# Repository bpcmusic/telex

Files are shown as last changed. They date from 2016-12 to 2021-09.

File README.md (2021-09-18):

# TELEX EURORACK EXPANDERS

The TELEX are a family of eurorack expanders that were initially designed to interface with the Monome Teletype to provide additional inputs and outputs. Utilizing the `II` bus (i2c) and having a flexible command set, there is no reason that these modules couldn't connect and extend other Monome Eurorack devices (even non-Eurorack devices that support II like the Aleph) or your own hardware projects.

Follow the conversation at [llllllll](http://llllllll.co/t/a-teletype-expander/1379).

## The Modules

The TELEXo (or TXo) is an output expander and the TELEXi (or TXi) is an input expander. They have little jumpers on the back so you can hook more than one of each module to your Teletype simultaneously. (Theoretically, up to eight of each type - though I’ve only tested six total modules at a time thus far. There will be a limit based on the II bus resistance - not sure what it is yet.)

* **TELEXo (TXo)**: a 4HP output module that provides 4 trigger outputs and 4 CV outputs addressable over `II`. Up to 8 can be independently addressed by the Teletype.

* **TELEXi (TXi)**: a 4HP input module that provides 4 control voltage potentiometers and 4 independent control voltage inputs. Up to 8 can be independently addressed by the Teletype.

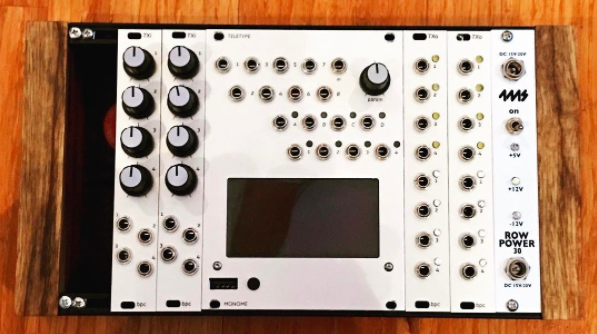
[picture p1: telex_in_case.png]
TELEX MODULES


## Teletype Firmware

We recommend the Teletype 2.0 BETA at this point. You can get it from this forum:

https://llllllll.co/t/teletype-2-0-beta-release-candidate-1-released-6th-june-2017/6939?u=bpcmusic

It is the bomb.

You can always head to Monome for the latest [Official Teletype Firmware](https://github.com/monome/teletype).

## TELEX Firmware

Download the latest TELEX firmware from the releases section of this site:

https://github.com/bpcmusic/telex/releases

### Installing Your Firmware

> **DO NOT POWER YOUR MODULE WHILE CONNECTING THE TEENSY VIA USB TO YOUR COMPUTER - THIS WOULD BE VERY BAD**

Ok. With that out of the way, here are some simple steps.

Firmware is loaded on the Teensy processor that piggybacks on the underside of your module. Doing so is pretty simple.

1. Download the Teensy Loader application for your operating system from https://www.pjrc.com/teensy/loader.html (if you don't have it already)
2. Download and unzip the latest TELEX firmware from https://github.com/bpcmusic/telex/releases
3. (optional) Carefully remove the Teensy from your module
4. Connect the Teensy to your computer via USB
5. Use your operating system specific instructions for the Teensy Loader to open the appropriate firmware in the Teensy loader and program it on your Teensy
6. Disconnect the Teensy from USB when the firmware has been loaded
7. Reattach the Teensy to your module if you removed it
8. Party.

### Compiling Your Own Firmware

Compiling the TELEX firmware is done using the [Arduino Development Environment](https://www.arduino.cc/en/Main/Software) and a few extensions.

* [Arduino Development Environment](https://www.arduino.cc/en/Main/Software)
* [Teensy-duino Add-On](https://www.pjrc.com/teensy/td_download.html)
* [i2c_t3 Library for Teensy](https://forum.pjrc.com/threads/21680-New-I2C-library-for-Teensy3)

Several additional libraries are included in the project due to the Arduino IDE's wonderful linking capabilities.

	IMPORTANT: overclock your Teensy 3.2 to 120 MHz in the IDE; Teensy 3.6 should be at 180 MHz

### Critical Startup Optimization for Compilation

> NOTE: this keeps changing in the Teensyduino application. I'm not finding this necessary anymore, but am leaving the old instructions in case anyone wants to fuss around with it. You can ignore for now.

If you want your TELEX to be ready when your Teletype has booted and is sending out the `I` script for the program that it is loading at startup, you need to make a change to the Teensy file "pins_teensy.c" in your Arduino hardware folder. For my mac, this is inside of the Arduino application package in:

`Contents\Java\hardware\teensy\avr\cores\teensy3\pins_teensy.c`

You need to change the values in the delay() calls - the original values are commented off to the right:

```
#if TEENSYDUINO >= 142
	delay(25);
	usb_init();
	delay(150); // 275
#else
	delay(50);
	usb_init();
	delay(125); // 350
#endif
```

For now, we edit this in-place. I know. We shuddered too. But, that seems to be the best way to make the change. Remember, you need to change it back for any other Arduino compilation you plan to do as it may have the device ready before all of your related components are - including the Teensy's USB interface.

## TELEX Command Reference

Reference documents for the commands supported by the TXo and TXi are located here:

* [Markdown Command Reference with Extra Descriptions](commands.md)
* [Printable Command Reference](extras/TELEX%20Command%20Reference.pdf)

The documents are a little behind the latest firmware; we're moving all operator definitions into the 2.0 documentation system which **is** up to date.

The latests ops are mentioned in this forum post, if you are curious. You need the 2.0 beta firmware (mentioned above) to access them.

https://llllllll.co/t/telex-teletype-expanders/1379/609?u=bpcmusic

## TELEXo

Each 4HP module adds 4 Trigger outputs and 4 Control Voltage outputs. 

All Teletype output functionality is supported by the TXo. Operators are near-identical for basic functionality, just put a "TO.” in front of the set you already know. The outputs are a little different; the triggers are +5V triggers and the CV outputs are bipolar (-10V to +10v) with 16 bit resolution over that range.

Extended functionality of the TXo starts with being able to specify longer values for slew and pulse times (in seconds and minutes). 

The TXo has the following “experimental” features for each of its four TR outputs:

- Configurable pulse dividers for each output
- Independent metronomes for each output that will pulse each output at intervals that can be set in milliseconds, seconds, minutes, and beats per minute (BPM)

The TXo also has the following “experimental” features for each of its four CV outputs:

- a quantizer with a dozen or so microtonal scales in addition to equal temperament
- an oscillator (not currently band-limited) that supports frequencies from LFO rates up to around 8kHz with variable morphing waveforms (sine, triangle, saw, variable width square, and noise), adjustable phase offset, and frequency slew (portamento)
- an AR (attack + release) envelope generator with times in milliseconds, seconds and minutes

These extended features, when combined together, can really push the envelope of the TXo’s processor and do some crazy stuff. For example: the output's envelope generator can act as a VCA, which turns the expander into a little 4-voice synth.

#### Links:

* [TXo Arduino Firmware](software/TELEXo)
* [TXo Module PCB](hardware/TELEXo/board)
* [TXo Module BOM](hardware/TELEXo/board/TELEXo-BOM.xlsx)
* [TXo 4HP Module Panel](hardware/TELEXo/panel)

## TELEXi

Each 4HP module adds 4 IN jacks and 4 PARAM knobs. 

* The IN jacks are bipolar (-10V to +10V).
* They jacks and knobs just like the Teletype IN and PARAM operators (TI.IN and TI.PARAM). 
* The TXi has some extended functionality where the TXi can do quantization for you and return note numbers against any one of its internal scales (there are about 12 or so). 
* Inputs are sampled with 13bit resolution.

#### Links:

* [TXo Arduino Firmware](software/TELEXi)
* [TXo Module PCB](hardware/TELEXi/board)
* [TXo Module BOM](hardware/TELEXi/board/TELEXi-BOM.xlsx)
* [TXo 4HP Module Panel](hardware/TELEXi/panel)

## Addressing Multiple TELEX Modules

Multiple TELEX modules are addressed using jumpers on the back of the unit. Theoretically, you can have up to eight of each type of unit on the same II bus. The addresses are non-conflicting between module types. For example, if you have one of each module, each would be unit #1 of that type and neither would have any address jumpers set.

The jumpers are oriented vertically and the rows are numbered from top to bottom:

* Row 1
* Row 2
* Row 3

Placing jumpers on rows in the following sequence allows you to designate the unit # (which is the binary representation of the rows plus one). X indicates the placement of a jumper.

| Row 1 | Row 2 | Row 3 | Unit # | Inputs/Outputs |
| --- | --- | --- | --- | --- |
| 0 | 0 | 0 | 1 | 1-4 |
| X | 0 | 0 | 2 | 5-8 |
| 0 | X | 0 | 3 | 9-12 |
| X | X | 0 | 4 | 13-16 |
| 0 | 0 | X | 5 | 17-20 |
| X | 0 | X | 6 | 21-24 |
| 0 | X | X | 7 | 25-28 |
| X | X | X | 8 | 28-32 |

## DIY Tips and Warnings

The modules are made up with two boards stacked on top of each other and a Teensy 3.2 riding piggyback. They are primarily 603 SMD parts with a few 805, 1206 and SMD ICs thrown in for good measure. If you have assembled any of mxmxmx’s DIY modules (Ornament + Crime, Terminal Tedium, etc.) you should have no problem with the expanders. They are not, however, a beginners project for SMD.

The DAC that is used for the TXo is the DAC8564 (Mouser P/N: 595-DAC8564ICPW; datasheet: http://www.ti.com/product/DAC8564). This part is used by a number of Eurorack modules - including Mutable's *Yarns* and *Ornament + Crime* by mxmxmx. It has tiny little SMD legs that can cause DIY cursing. ;)

#### Use the Build Maps

The build maps are PDF files that have one page per component per side per board showing you all the places that component goes. This saves a ton of time and avoids the pain-in-the-ass component hunt. They are linked below - but check out the example below:

Build Map Sample

Thanks to [c1t1zen](https://www.instagram.com/c1t1zen/) for the idea. :)

#### Crazy Board Naming

I have a goofy naming convention for the boards. It is confusing. But, I embraced the organic silliness. The "Top" Board is the one behind the panel. The "Bottom" Board is the one facing the back of your case. The side of the board with the name of the unit and board on it is considered the "Top" of the board. The other side is considered the bottom. This means The boards and sides are like this:

- **Top Top** - facing the panel; has the jacks, pots and LEDs
- **Top Bottom** - the back-side of the one facing the panel with a small handful of components
- **Bottom Bottom** - faces the Top Bottom on the "back board" of the unit
- **Bottom Top** - faces the back of your case; has the Teensy, power and jumpers mounted on it

Stupid, I know. But it makes a certain kind of back assward sense.

#### Balancing Headers IMPORTANT

In addition to the two signal headers that connect the boards, there are a pair of two pin connectors that provide balance at the top and the bottom of the boards. Keep the following tips in mind:

> The top connector for both modules needs to be installed before the component that it sits behind it is placed. The header pins on the Top Top side should be as near flush as possible. They aid in connecting both boards ground planes, so you don't want them shorting out to the jack (TXo) or the potentiometer (TXi). I actually trim them to be board-level prior to soldering so that they are as flat as possible. I also bend the front foot of the potentiometer (TXi) out of the way a bit so as to avoid contact.

#### Stencil Frames are your Friends

There are a bunch of 3D printable frames available for you to help your build process. As there are SMD components on both sides of the three of the four boards across the two modules, these frames help lay the boards flat for the application of solder paste and/or manual soldering of the components. They save you a ton of time and frustration. They are your friends.

There are also MULTI files for three of the dual-sided boards that will help you hold eight boards next to each other at a time. These are really handy if you are building in bulk. All of the files are in the stencil_frame folders inside of the hardware / board folders.

3D Prints were tested on a Prusa i3 MK2 with PLA filament.

### TXi Build Files

[Explore the repository for all kinds of support files](hardware/TELEXi). Here are some of the key ones:

* [TXi Schematic](hardware/TELEXi/board/Telex-I%20Schematic.pdf)
* [TXi Gerbers Top](hardware/TELEXi/board/gerbers/TI-TOP-1.1.zip)
* [TXi Gerbers Bottom](hardware/TELEXi/board/gerbers/TI-BOT%201.1A.zip)
* [TXi BOM](hardware/TELEXi/board/TELEXi-BOM.xlsx)
* [TXi Bottom Top Build Map](hardware/TELEXi/board/build_map/bt/txi_bt_build_map.pdf)
* [TXi Bottom Bottom Build Map](hardware/TELEXi/board/build_map/bb/txi_bb_build_map.pdf)
* [TXi Top Top Build Map](hardware/TELEXi/board/build_map/tt/txi_tt_build_map.pdf)
* [TXi Top Bottom Build Map](hardware/TELEXi/board/build_map/tb/txi_tb_build_map.pdf)
* [TXi Panel Files](hardware/TELEXi/panel)
* [TXi Stencil Frames](hardware/TELEXi/board/stencil_frame)

### TXo Build Files

[Explore the repository for all kinds of support files](hardware/TELEXo). Here are some of the key ones:

* [TXo Schematic](hardware/TELEXo/board/Telex-O%20Schematic.pdf)
* [TXo Gerbers Top](hardware/TELEXo/board/gerbers/TO-TOP-1.1.zip)
* [TXo Gerbers Bottom](hardware/TELEXo/board/gerbers/TO-BOT-1.1.zip)
* [TXo BOM](hardware/TELEXo/board/TELEXo-BOM.xlsx)
* [TXo Bottom Top Build Map](hardware/TELEXo/board/build_map/bt/txo_bt_build_map.pdf)
* [TXo Bottom Bottom Build Map](hardware/TELEXo/board/build_map/bb/txo_bb_build_map.pdf)
* [TXo Top Top Build Map](hardware/TELEXo/board/build_map/tt/txo_tt_build_map.pdf)
* [TXo Top Bottom Build Map](hardware/TELEXo/board/build_map/tb/txo_tb_build_map.pdf)
* [TXo Panel Files](hardware/TELEXo/panel)
* [TXo Stencil Frames](hardware/TELEXo/board/stencil_frame)

## Thanks
* Brian Crabtree and Kelli Cain for creating [Monome](http://monome.org) and their awesome, open Eurorack modules (including the Teletype which started this all).

* [Galapagoose](http://llllllll.co/users/galapagoose/activity) for being an endlessly patient mentor helping get the circuit design and layout sorted. These modules wouldn't exist without his help.

* [Tom Erbe](http://www.soundhack.com/) for teaching me all about this stuff at CalArts back in the dark ages.

* Ezra Buchla and Brian for birthing the beautiful and ambitious Aleph and endowing it with an `II` jack.

* Tom Whitwell of [Music Thing Modular](http://musicthing.co.uk/modular/) and his open sharing of the Teensy 3.1 powered, Bad-Assed [RadioMusic](https://github.com/TomWhitwell/RadioMusic/wiki).

* Émilie Gillet at [Mutable Instruments](http://mutable-instruments.net/) for her fantastic modules, excellent design, impressive implementation skills and commitment to open hardware. 

* Jim Matheson of Neutron Sound and his fantastic Teensy 3.1 powered [Orgone Accumulator](http://neutron-sound.com/noa.html).

* PJRC for making the awesome [Teensy](https://www.pjrc.com/teensy/index.html).

* The community at [llllllll](http://llllllll.co) for being so supportive and patient as I've lumbered my way through making these things.

---

These modules are open source. Hardware is released under the cc-by-sa-4.0 license and the source code is released under the MIT license.

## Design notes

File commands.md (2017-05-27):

# TELEX Command Reference

This document outlines the commands for the open source Teletype Expanders TELEXo and TELEXi. You can also use this [Printable Command Reference](extras/TELEX Command Reference.pdf).

#### Changelog

The document's version history - for those of you that follow along. ;)

**Revision v.13y** - 18 February 2017

* added TXo commands for setting repeat counter for TR.M events

**Revision v.13x** - 18 February 2017

* added TXi commands for mapping inputs and param knobs
* added TXo commands for setting cycle length and trigger length
* added TXo commands for setting repeat counter for TR.M events

**Revision v.13w** - 7 February 2017

* added [scanner_darkly](https://github.com/scanner-darkly)'s awesome morphing waveform support for WAVE
* added [scanner_darkly](https://github.com/scanner-darkly)'s super useful oscillator phase offset

**Revision v.13p** - 14 January 2017

* added the extended commands for TO.TR; four independent metronomes and pulse dividers

**Revision v.13c** - 7 January 2017

* changed the extended commands for TIME and SLEW to use a period (.) to delimit the seconds and minutes extensions. For example: TO.TR.TIME.S
* reduced the size of the CALLIBRATE to CALIB command for the TXo

**Revision v.13b** - 16 December 2016

* first version of the command reference document

#### Notes

* **Basic Commands** represent commands that have 1 to 1 equivalents in the Teletype command set
* **Extended Commands** represent commands that are new to the expanders but have close equivalents in the Teletype command set
* **Experimental Commands** are commands that are new functionality provided by the expanders; they push the expanders to the edge of performance and should be considered "dangerously fun"
* **n** represents the number of outputs or inputs that you have added to your Teletype (4 of each type for each expander)
* **x** represents the expander unit as opposed to an output (1 for each expander)
* **&alpha;** represents the value that you are supplying to an operator that takes a parameter
* **&alpha;** values for control voltages are *bipolar* on the TELEXo - they accept values between -16384 to 16383

## TELEXo (TXo)

#### TXo Trigger Output (TR) Basic Commands

Command  | Description 
------------- | ------------- 
TO.TR 1-n &alpha;   | Set TR value to &alpha; (0/1)    
TO.TR.TOG 1-n  | Toggle TR
TO.TR.PULSE 1-n | Pulse TR using TO.TR.TIME/S/M as an interval
TO.TR.TIME 1-n &alpha; | time for TR.PULSE; &alpha; in milliseconds
TO.TR.POL 1-n &alpha; | polarity for TO.TR.PULSE set to &alpha; (0-1)

#### TXo Trigger Output (TR) Extended Commands

Command  | Description 
------------- | ------------- 
TO.TR.TIME.S 1-n &alpha; | time for TR.PULSE; &alpha; in seconds
TO.TR.TIME.M 1-n &alpha; | time for TR.PULSE; &alpha; in minutes

#### TXo Trigger Output (TR) Experimental Commands - Divider + Metronomes

Command  | Description 
------------- | ------------- 
TO.TR.PULSE.DIV 1-n &alpha; | pulse divider for TR output; &alpha; in # of pulses
TO.TR.M 1-n &alpha; | time for TR.M; &alpha; in milliseconds
TO.TR.M.S 1-n &alpha; | time for TR.M; &alpha; in seconds
TO.TR.M.M 1-n &alpha; | time for TR.M; &alpha; in minutes
TO.TR.M.BPM 1-n &alpha; | time for TR.M; &alpha; in Beats Per Minute
TO.TR.M.ACT 1-n &alpha; | activates the metronome for the TR output; &alpha; (0=off; 1=on)
TO.TR.M.COUNT 1-n &alpha; | sets the number of repeats before deactivating (0=infinity)
TO.TR.M.SYNC 1-n | synchronizes the metronome on the device #
TO.TR.WIDTH 1-n &alpha; | time for TR.PULSE; &alpha; percentage of TR.M

#### TXo Control Voltage (CV) Basic Commands

Command  | Description 
------------- | ------------- 
TO.CV 1-n &alpha; | CV target &alpha; (bipolar)
TO.CV.SLEW 1-n &alpha; | CV slew time; &alpha; in milliseconds
TO.CV.SET 1-n &alpha; | set CV to &alpha; (bipolar); ignoring SLEW
TO.CV.OFF 1-n &alpha; | CV offset; &alpha; added at final stage 

#### TXo Control Voltage (CV) Extended Commands

Command  | Description 
------------- | ------------- 
TO.CV.SLEW.S 1-n &alpha; | CV slew time; &alpha; in seconds
TO.CV.SLEW.M 1-n &alpha; | CV slew time; &alpha; in minutes
TO.CV.QT 1-n &alpha; | CV target &alpha;; quantized to output's current CV.SCALE
TO.CV.QT.SET 1-n &alpha; | set CV to &alpha;; quantized to output's current CV.SCALE; ignoring SLEW
TO.CV.N 1-n &alpha; | CV target note # &alpha; in output's current CV.SCALE
TO.CV.N.SET 1-n &alpha; | set CV to note # &alpha; in output's current CV.SCALE; ignoring SLEW
TO.CV.SCALE 1-n &alpha; | select scale # &alpha; for individual CV output; see quantization scale reference below

#### TXo Control Voltage (CV) Experimental Commands - Oscillator Functions

Note: to start oscillation, set the frequency for the CV output to a value greater than zero. To return it to basic functionality, set it back to zero (0). When in oscillation mode, the current CV value sets the peak for the waveform - think of it like a volume or range control.

Command  | Description 
------------- | ------------- 
TO.OSC 1-n &alpha; | targets oscillation to &alpha; (1v/oct translated)
TO.OSC.SET 1-n &alpha; | sets oscillation to &alpha;; ignores OSC.SLEW
TO.OSC.QT 1-n &alpha; | targets oscillation to &alpha; (1v/oct translated); quantized to current OSC.SCALE
TO.OSC.QT.SET 1-n &alpha; | sets oscillation to &alpha; in current OSC.SCALE; ignores OSC.SLEW
TO.OSC.N 1-n &alpha; | targets oscillation to note # &alpha;; quantized to current OSC.SCALE
TO.OSC.N.SET 1-n &alpha; | sets oscillation to note # &alpha; in current OSC.SCALE; ignores OSC.SLEW
TO.OSC.FQ 1-n &alpha; | targets oscillation to frequency &alpha; in Hz
TO.OSC.FQ.SET 1-n &alpha; | sets oscillation to frequency &alpha; in Hz; ignores OSC.SLEW
TO.OSC.LFO 1-n &alpha; | targets oscillation to frequency &alpha; in mHz (millihertz: 10^-3 Hz)
TO.OSC.LFO.SET 1-n &alpha; | sets oscillation to frequency &alpha; in mHz (millihertz: 10^-3 Hz); ignores OSC.SLEW
TO.OSC.WAVE 1-n &alpha; | set the waveform to sine (0), triangle (1000), saw (2000), pulse (3000), or noise (4000). Range is from 0 to 4999. Oscillator shape is blended in between the "pure" values.
TO.OSC.SYNC 1-n | resets the phase of the oscillator to zero
TO.OSC.PHASE 1-n &alpha; | sets the phase offset of the oscillator to &alpha; (0 to 16384) - range of one cycle;
TO.OSC.WIDTH 1-n &alpha; | sets the width of the pulse  wave (3) to &alpha; (0 to 100)
TO.OSC.RECT 1-n &alpha; | rectifies the polarity of the oscillator to &alpha; (-2 to 2); see rectification reference
TO.OSC.SLEW 1-n &alpha; | sets the slew time for the oscillator (portamento) to &alpha; (milliseconds)
TO.OSC.SLEW.S 1-n &alpha; | sets the slew time for the oscillator (portamento) to &alpha; (seconds)
TO.OSC.SLEW.M 1-n &alpha; | sets the slew time for the oscillator (portamento) to &alpha; (minutes)
TO.OSC.SCALE 1-n &alpha; | sets the quantization scale for the oscillator to scale # &alpha; (listed below)
TO.OSC.CYC 1-n &alpha; | targets the cycle length for the oscillator to &alpha; (milliseconds)
TO.OSC.CYC.S 1-n &alpha; | targets the cycle length for the oscillator to &alpha; (seconds)
TO.OSC.CYC.M 1-n &alpha; | targets the cycle length for the oscillator to &alpha; (minutes)
TO.OSC.CYC.SET 1-n &alpha; | sets the cycle length for the oscillator to &alpha; (milliseconds)
TO.OSC.CYC.S.SET 1-n &alpha; | sets the cycle length for the oscillator to &alpha; (seconds)
TO.OSC.CYC.M.SET 1-n &alpha; | sets the cycle length for the oscillator to &alpha; (minutes)

#### TXo Control Voltage (CV) Experimental Commands - Envelope Generator

Note: when you activate the envelope (using ENV.ACT) your CV output will drop to zero. You need to trigger the envelope (ENV.TRIG) in order to get it to play. This will interact with your currently set CV value for the output making that the (bipolar capable) peak for the envelope. Also, this will interact with the oscillator as well and become a virtual VCA for its output.

Command  | Description 
------------- | ------------- 
TO.ENV.ACT 1-n &alpha; | activates the envelope generator for the CV output; &alpha; (0 = off; 1 = on)
TO.ENV.ATT 1-n &alpha; | attack time for the envelope; &alpha; in milliseconds
TO.ENV.ATT.S 1-n &alpha; | attack time for the envelope; &alpha; in seconds 
TO.ENV.ATT.M 1-n &alpha; | attack time for the envelope; &alpha; in minutes
TO.ENV.DEC 1-n &alpha; | decay time for the envelope; &alpha; in milliseconds 
TO.ENV.DEC.S 1-n &alpha; | decay time for the envelope; &alpha; in seconds
TO.ENV.DEC.M 1-n &alpha; | decay time for the envelope; &alpha; in minutes
TO.ENV.TRIG 1-n | triggers the envelope to play

#### TXo Global Commands

This command affects both trigger (TR) and control voltage (CV) outputs.

Command  | Description 
------------- | ------------- 
TO.KILL | cancels TR pulses and CV slews 

#### Rectification Reference

There are several rectification modes available in the oscillator. They are listed below:

Mode | Behavior
--- | ---
-2 | inverts positive values making them negative
-1 | omits all positive values
0 | no rectification; wave is unaffected bipolar
1 | omits all negative values
2 | inverts negative values making them positive

## TELEXi (TXi)

#### TXi Basic Commands

Command  | Description 
------------- | ------------- 
TI.IN 1-n | reads the value of the CV input jack (-16384 to 16383)
TI.PARAM 1-n | reads the value of the PARAM knob (0 to 16383) 

#### TXi Extended Commands

Command  | Description 
------------- | ------------- 
TI.IN.QT 1-n | return the quantized value for the IN jack; uses input's IN.SCALE
TI.IN.N 1-n | return the quantized note number for the IN jack; uses the input's IN.SCALE
TI.IN.SCALE 1-n &alpha; | sets the current scale for the input to &alpha;; see scale reference below
TI.IN.MAP 1-n &alpha; &beta; | maps the IN values to the range &alpha; - &beta;
TI.PARAM.QT 1-n | return the quantized value for the PARAM knob; uses knob's PARAM.SCALE
TI.PARAM.N 1-n | return the quantized note number for the PARAM knob; uses knob's PARAM.SCALE
TI.PARAM.SCALE 1-n &alpha; | sets the current scale for the param knob to &alpha;; see scale reference below
TI.PARAM.MAP 1-n &alpha; &beta; | maps the PARAM values to the range &alpha; - &beta;

#### TXi Experimental Commands

The calibration settings allow you to scale your input values for the IN jacks and the PARAM knobs to compensate for component tolerances. The calibration procedures are listed in the Calibration Details section.

*NOTE: Only the TXi currently has calibration capabilities; these features have not been implemented for the TXo for performance reasons - though, if they are desired, it would be possible to port them over. Go Open Source!*

Command  | Description 
------------- | ------------- 
TI.IN.CALIB 1-n &alpha; | calibrates the scaling for the IN jack; see calibration details below
TI.PARAM.CALIB 1-n &alpha; | calibrates the scaling for the PARAM knob; see calibration details below
TI.STORE 1-x | stores the calibration data for the expander to its flash memory
TI.RESET 1-x | resets the calibration data to factory defaults

#### TXi Calibration Details

Calibration for the input module works as follows:

**IN Calibration**

1. Send a -10V signal to the input Z
2. Send the command 'TI.IN.CALIBRATE Z -1'
3. Send a 0V signal to the input Z
4. Send the command 'TI.IN.CALIBRATE Z 0'
5. Send a 10V signal to the input Z
6. Send the command 'TI.IN.CALIBRATE Z 1'

**PARAM Calibration**

1. Turn the PARAM knob Z all the way to the left
2. Send the command 'TI.PARAM.CALIBRATE Z 0'
3. Turn the PARAM knob Z all the way to the right
4. Send the command 'TI.PARAM.CALIBRATE Z 1'

**Save and Reset**

* You can save the calibration data for a device by sending 'TI.STORE N'. N is the number of the device - not the number of an input.

* You can reset the calibration data for a device by sending 'TI.RESET N'. N is the number of the device - not the number of an input.

## Quantization Scale Reference

Scale Number | Scale Name
--- | ---
0 | Standard 12 Tone Equal Temperament **[DEFAULT]** 
1 | 12-tone Pythagorean scale
2 | Vallotti & Young scale (Vallotti version) also known as Tartini-Vallotti (1754)
3 | Andreas Werckmeister's temperament III (the most famous one, 1681)
4 | Wendy Carlos' Alpha scale with perfect fifth divided in nine
5 | Wendy Carlos' Beta scale with perfect fifth divided by eleven
6 | Wendy Carlos' Gamma scale with third divided by eleven or fifth by twenty
7 | Carlos Harmonic & Ben Johnston's scale of 'Blues' from Suite f.micr.piano (1977) & David Beardsley's scale of 'Science Friction'
8 | Carlos Super Just
9 | Kurzweil "Empirical Arabic"
10 | Kurzweil "Just with natural b7th", is Sauveur Just with 7/4
11 | Kurzweil "Empirical Bali/Java Harmonic Pelog"
12 | Kurzweil "Empirical Bali/Java Slendro, Siam 7"
13 | Kurzweil "Empirical Tibetian Ceremonial"
14 | Harry Partch's 43-tone pure scale
15 | Partch's Indian Chromatic, Exposition of Monophony, 1933.
16 | Partch Greek scales from "Two Studies on Ancient Greek Scales" on black/white

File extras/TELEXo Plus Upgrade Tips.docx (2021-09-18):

Thanks for grabbing a TXo+ Upgrade – the upgrade for those with discerning tastes in output expanders. This kit includes a hand-modified Teensy 3.6 and a bunch of capacitors that you don’t really need. No worries on that last part; all will be explained below.

What to Expect

When running on the Teensy 3.6, the TXo firmware does a few new things:

- Improved Sampling Rate - increased to 25kHz from the TXo’s 15.625kHz
- Improved Quality when Combining Features with Oscillation - the stock TXo disables interpolation if more than one advanced feature is used at a time for a CV output (envelopes, wave morphing, pitch slew, etc). The TXo+ always uses interpolation which increases the accuracy and lowers distortion.
- Enhanced sawtooth and square waves using the PolyBlep technique in order to reduce aliasing.
- More Morphing Wavetables - the TXo+ has 327 different waveforms on board (up from the TXo’s 45). Values range between 0 and 32699. Every 100 you get another “pure” waveform. 32600 should be random noise.

The commands are the same between the TXo and the TXo+. The only difference is the TO.OSC.WAVE as mentioned above. You don’t have to learn anything else if you are familiar with your TXo.

Now, here is the important bit: your TXo will still alias like crazy when used as an oscillator without additional filtration. It was designed as a CV device and only lightly filters the output. You might like the sound this way. I do.

You can clean things up with the right additional filtration (at 12.5k). This primarily will benefit the primitives (sine, square, saw, and triangle); extended waveforms will still alias as the expander doesn’t have the horsepower to oversample.

How to Install the Upgrade

There are two ways for you to do this. The reasonable way and the ridiculous way. The ridiculous way, while being ridiculous, includes the steps of the reasonable way. So, as with all things, let’s start reasonable and then get ridiculous.

Reasonable Install Steps

1. Carefully extract your TXo from your case.
2. Make sure you are grounded and not full of static electricity. (Good idea to banish the cat until you are done.)
3. Grip the Teensy processor on the back and delicately lift it out of its socket with even force on both sides. You might need to rock it a bit – just don’t do too much of that or you will bend the pins.
4. Remove the Teensy 3.6 with attached TeensyHelper from the antistatic bag.
5. Insert the old Teensy 3.2 into the empty antistatic bag and seal it.
6. Carefully insert the Teensy 3.6 into headers on the TXo body with the same orientation as the previous Teensy. (USB socket facing up and SD card facing down relative to the module.)
7. Make sure everything is seated properly and happy – including the various boards of your TXo.
8. Connect up your module to power and i2c and run a test to see if you get blinking lights and signal. (See “troubleshooting” below if you have problems.)
9. Reinstall your module.
10. Party.

Ridiculous Install Steps

This part is stupid. Best you ignore it.

We’ve included four capacitors with your upgrade. Trust us when we say that you don’t need them. Like, not at all. You won’t hear a difference. You won’t see a difference. You will more likely bork your TXo if you try to swap them out.

Why did we include them? We are asking ourselves the same question.

Maybe it was to torture you? We know that they would bug you. Disappoint you that they aren’t installed. That having them in your studio would be a constant reminder of incompleteness. A reminder of how your TXo+ is less than other TXo+ in the world.

Nah. They really don’t matter.

We included them for the sake of completeness – which for some reason is important to us. What they do is raise the cutoff point of the 1-pole filter on the TXo’s output so that it matches the new sampling rate. How much? Not much. Somewhere between 4-5 kHz.

Now, when you hear filter you are most likely thinking Filter. That’s not what we are talking about here. A 1-pole filter is a wimpy thing with a super gradual cutoff. It gets beat up after school. It has self-esteem problems. This is why we recommend more filtration if you want to get pure tones out of your TXo+.

We’ve included six capacitors that swap out for C102, C2, C3, and C4 on the TXo. Does your head hurt now? Think we can’t count? Come on; we included two extra just in case you sneeze while futzing when them (even though we told you not to).

Anyway, you can find all of the details on the github page for the module. We’re not including it here in order to avoid tempting you to try to swap them out – because you don’t need to.

Like, don’t. Just let it be.

You really don’t need them.

Troubleshooting

Your upgrade was installed and tested at our factory and should be in great shape. That is what the little orange dot means on the SD card.

Ok. it isn’t a “factory”, per se. It is a messy-as-hell guest bedroom that has never accommodated a guest - outside of the four-legged and furry kind.

Regardless, it was working when we sent it. The most common problem we have seen is with the machined headers that connect the two units. Sometimes they are so perfectly aligned that a pin or two makes poor contact. This will manifest itself in no CV (all values at -10), a trigger that doesn’t fire, an LED or two that doesn’t light up, or an unresponsive module.

The way to correct this is to provide a very slight bend to pins, alternating the direction (in vs out) until everything is happy. They are delicate, so you have to be extremely careful when doing this. Do them one at a time and test that you can still seat the processor.

Any other problems? Give a shout on lines (https://llllllll.co/) in the TELEX thread.

GOOD LUCK!!

b

TELEXo Plus Upgrade

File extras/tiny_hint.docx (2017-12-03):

A TINY HINT

Ensure that your TELEX boards and processor are properly seated after shipment. This is also a good thing to do after handling of any kind. Frankly, checking that your boards are properly connected should be the first thing you do if your unit seems unresponsive.

AN EVEN SMALLER HINT

If you are planning to travel with your TELEX, consider using thread or small rubber bands to keep the boards well-seated during rough travel. Superglue, chewing gum, and duct tape are not recommended for this purpose.

A LUDICROUSLY SMALL HINT

If you want your TELEX to be as thin and as securely assembled as possible, some people have desoldered the female headers and then soldered the boards together. Please, don’t try this if you don’t know what you are doing and have the proper equipment. Regardless, we take no responsibility for the chaos you cause in attempting this. If you and your pets survive, share some pictures!

A TINY HINT

Ensure that your TELEX boards and processor are properly seated after shipment. This is also a good thing to do after handling of any kind. Frankly, checking that your boards are properly connected should be the first thing you do if your unit seems unresponsive.

AN EVEN SMALLER HINT

If you are planning to travel with your TELEX, consider using thread or small rubber bands to keep the boards well-seated during rough travel. Superglue, chewing gum, and duct tape are not recommended for this purpose.

A LUDICROUSLY SMALL HINT

If you want your TELEX to be as thin and as securely assembled as possible, some people have desoldered the female headers and then soldered the boards together. Please, don’t try this if you don’t know what you are doing and have the proper equipment. Regardless, we take no responsibility for the chaos you cause in attempting this. If you and your pets survive, share some pictures!

A TINY HINT

Ensure that your TELEX boards and processor are properly seated after shipment. This is also a good thing to do after handling of any kind. Frankly, checking that your boards are properly connected should be the first thing you do if your unit seems unresponsive.

AN EVEN SMALLER HINT

If you are planning to travel with your TELEX, consider using thread or small rubber bands to keep the boards well-seated during rough travel. Superglue, chewing gum, and duct tape are not recommended for this purpose.

A LUDICROUSLY SMALL HINT

If you want your TELEX to be as thin and as securely assembled as possible, some people have desoldered the female headers and then soldered the boards together. Please, don’t try this if you don’t know what you are doing and have the proper equipment. Regardless, we take no responsibility for the chaos you cause in attempting this. If you and your pets survive, share some pictures!

A TINY HINT

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

AN EVEN SMALLER HINT

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

A LUDICROUSLY SMALL HINT

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

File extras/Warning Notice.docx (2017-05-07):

WARNING

DO NOT connect your module’s Teensy processor to USB while it is connected to Eurorack power. This will cause bad things to happen. Chernobyl-style bad things. Resist the temptation.

To upgrade your firmware, disconnect your module or simply remove the Teensy from the back of the module and connect it to your computer. Follow the procedure for loading firmware onto the Teensy that is appropriate for your operating system.

If you wish to debug the module via USB, you will need to separate VIN from VUSB on the underside of the Teensy. This is a simple procedure that should be done carefully to ensure that you don’t damage your Teensy, module, computer, or fabric of the universe.

TELEX Addendum 20170107-091371c

WARNING

DO NOT connect your module’s Teensy processor to USB while it is connected to Eurorack power. This will cause bad things to happen. Chernobyl-style bad things. Resist the temptation.

To upgrade your firmware, disconnect your module or simply remove the Teensy from the back of the module and connect it to your computer. Follow the procedure for loading firmware onto the Teensy that is appropriate for your operating system.

If you wish to debug the module via USB, you will need to separate VIN from VUSB on the underside of the Teensy. This is a simple procedure that should be done carefully to ensure that you don’t damage your Teensy, module, computer, or fabric of the universe.

TELEX Addendum 20170107-091371c

WARNING

DO NOT connect your module’s Teensy processor to USB while it is connected to Eurorack power. This will cause bad things to happen. Chernobyl-style bad things. Resist the temptation.

To upgrade your firmware, disconnect your module or simply remove the Teensy from the back of the module and connect it to your computer. Follow the procedure for loading firmware onto the Teensy that is appropriate for your operating system.

If you wish to debug the module via USB, you will need to separate VIN from VUSB on the underside of the Teensy. This is a simple procedure that should be done carefully to ensure that you don’t damage your Teensy, module, computer, or fabric of the universe.

TELEX Addendum 20170107-091371c

WARNING

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

TELEX Addendum 20170107-091371c

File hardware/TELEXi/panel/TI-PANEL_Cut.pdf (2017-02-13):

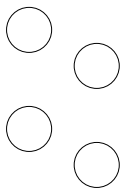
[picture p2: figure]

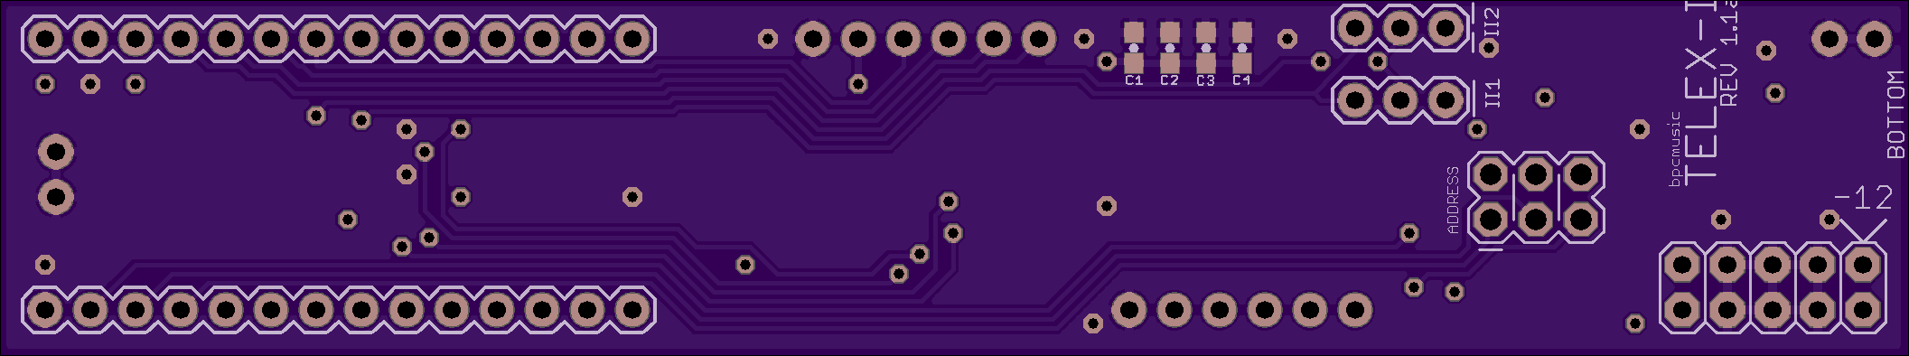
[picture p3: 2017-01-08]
hardware/TELEXi/board/images/TXi_Bottom_Top.png

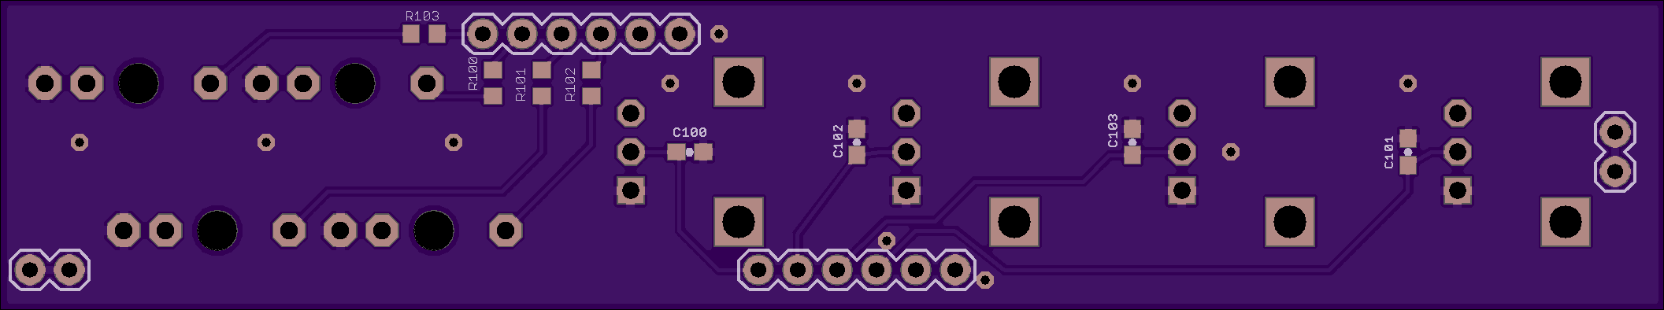
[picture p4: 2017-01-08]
hardware/TELEXi/board/images/TXi_Top_Bottom.png

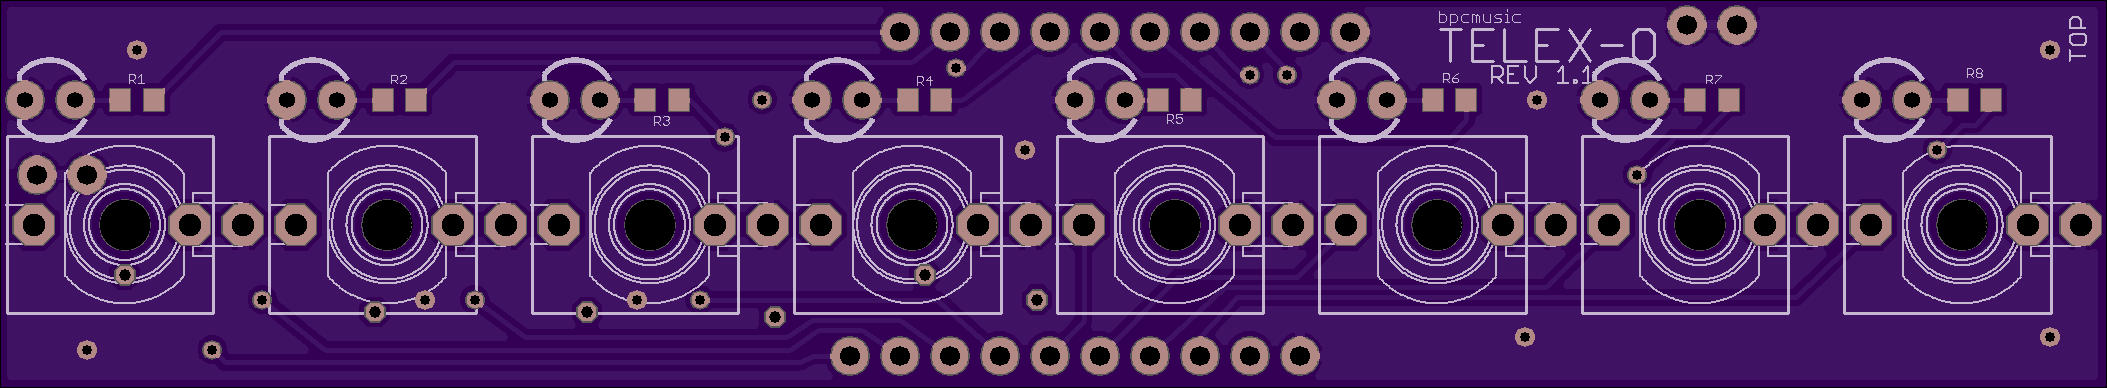
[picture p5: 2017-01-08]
hardware/TELEXo/board/images/TXo_Top_Top.png

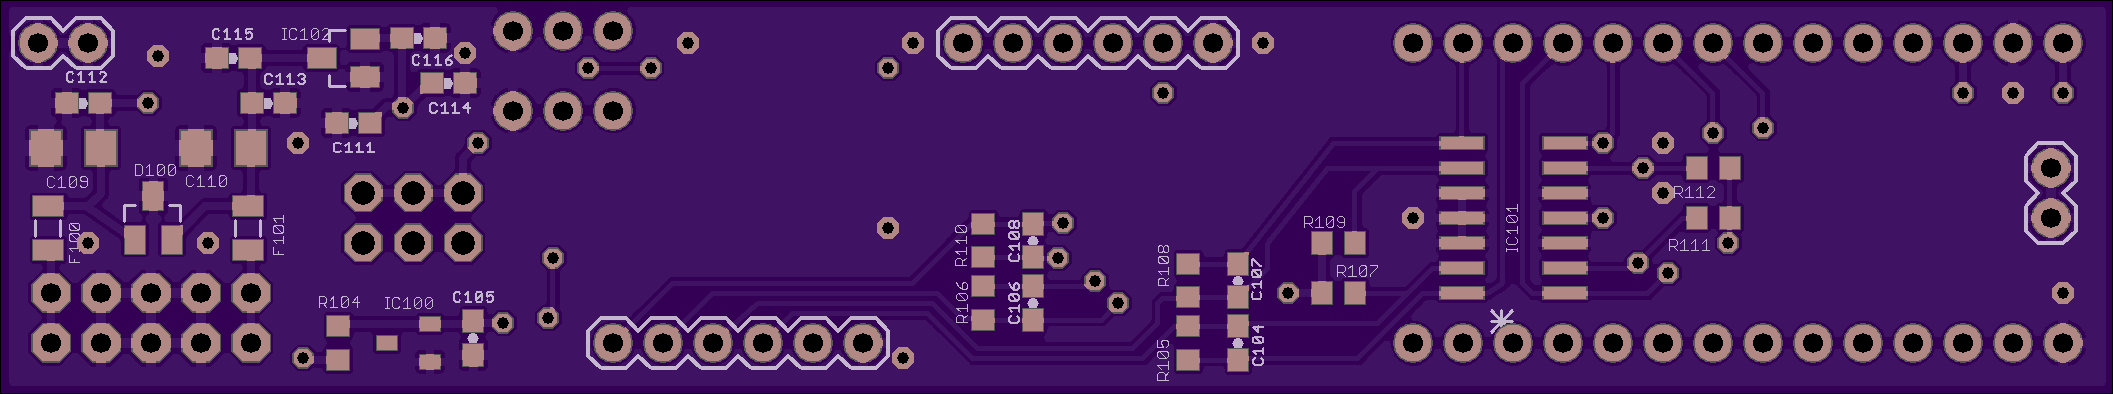
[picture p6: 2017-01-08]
hardware/TELEXi/board/images/TXi_Bottom_Bottom.png

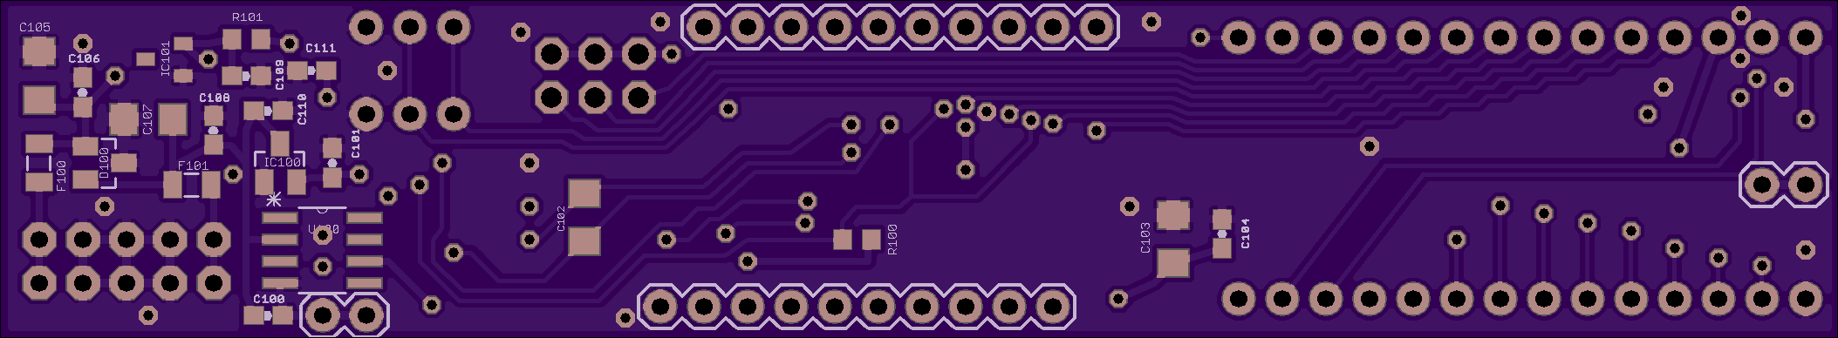
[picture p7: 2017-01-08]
hardware/TELEXo/board/images/TXo_Bottom_Bottom.png

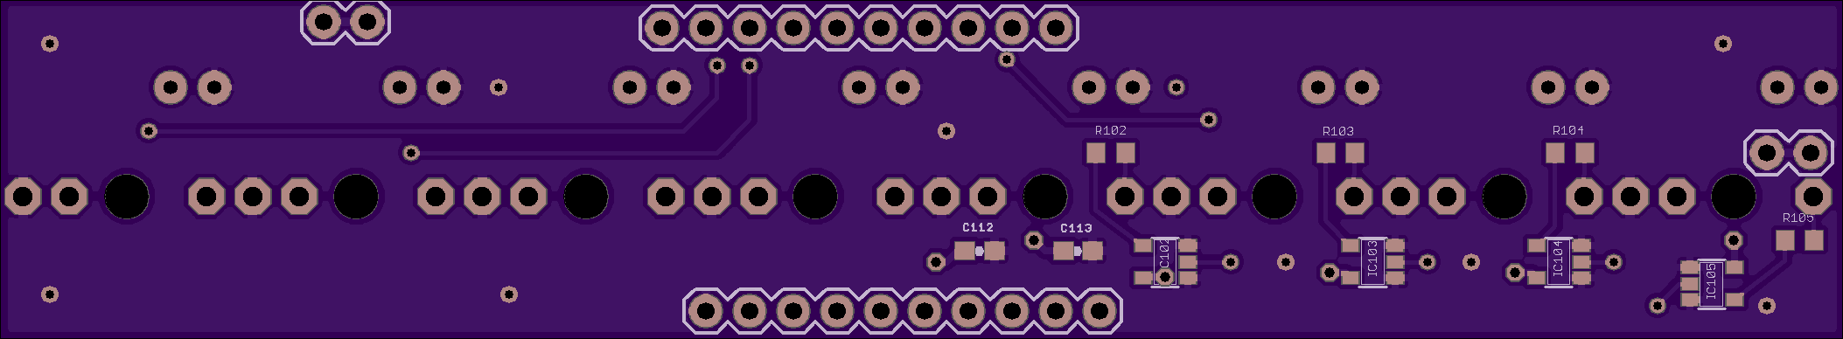
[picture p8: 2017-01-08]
hardware/TELEXo/board/images/TXo_Top_Bottom.png

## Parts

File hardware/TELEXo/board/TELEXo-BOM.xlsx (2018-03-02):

Qty | Value | Device | Package | Description | TopTop | TopBottom | BottomBottom | BottomTop | OC_MOUSER | URL | Notes
2 | 0805L010 | 0805L010 | 0805L | Polyfuse Resettable PTC |  |  | F100,F101 |  | 576-0805L010
2 | 1x03 MALE | 1x03M | 1x03M | 1x3 Header, Male |  |  |  |  |  |  | i2c Connectors; Standard Headers
2 | 1x10 FEMALE | 1x10F | 1x10F | 1x10 Header, Female |  |  |  |  |  |  | Board Interconnects; Safe to Substutite Machined Headers
2 | 1x10 MALE | 1x10M | 1x10M | 1x10 Header, Male |  |  |  |  |  |  | Board Interconnects; Safe to Substutite Machined Headers
2 | 1x14 FEMALE | 1x14F | 1x14F | 1x14 Header, Female |  |  |  |  |  |  | Teensy Interconnects; Safe to Substitute Machined Headers
2 | 1x14 MALE | 1x14M | 1x14M | 1x14 Header, Male |  |  |  |  |  |  | Teensy Interconnects; Safe to Substitute Machined Headers
1 | 2x03 MALE | 2x03M | 2x03M | 2x3 Header, Male |  |  |  |  |  |  | Jumpers; Standard Headers
1 | 2x05 MALE | 2x05M | 2x05M | Europower 2x5 |  |  |  |  |  |  | Europower Connector
4 | 74AHCT1G125DBV | 74AHCT1G125DBV | SOT23-5 | Single Bus Buffer Gate |  | IC102,IC103,IC104,IC105 |  |  | 595-SNAHCT1G125DBVR
1 | BAS70-04 | BAS70-04 | SOT23 | Schottky Diodes |  |  | D100 |  | 771-BAS70-04-T/R
8 | .1u | CAP0603-CAP | 0603-CAP | Capacitor; >=16V; 5% |  | C112,C113 | C100,C104,C106,C108,C109,C111 |  | 581-06033C104JAT2A
1 | .22u | CAP0603-CAP | 0603-CAP | Capacitor; >=16V; 10% |  |  |  | C1 | 810-C1608X7R1H224KAE
2 | 1u | CAP0603-CAP | 0603-CAP | Capacitor; >=16V; 10% |  |  | C101,C110 |  | 81-GCJ188R71E105KA1D
2 | 10uf | CAP1206 | 1206 | Capacitor; >=16V; 10% |  |  | C105, C107 |  | 81-GRM31CR71E106KA12
4 | 180p | CAP1206 | 1206 | Capacitor; >=16V; 1% |  |  | C102 | C2,C3,C4 | 77-VJ1206A181FXACBC |  | Substitue 110p if you plan to use a Teensy 3.6; Mouser PN 80-C1206C111J1G
1 | 3.3u | CAP1206 | 1206 | Capacitor; >=16V; 10% |  |  | C103 |  | 810-C3216X7R1H335K
1 | DAC8564 | DAC8564 | SOP65P640X120-16N | DAC |  |  |  | U1 | 595-DAC8564ICPW
8 | EURO_JACKS-7 | EURO_JACKS-7 | WQP_PJ_301M | Thonkiconn 3.5mm |  |  |  |  |  | https://www.thonk.co.uk/shop/3-5mm-jacks/ | "Thonkiconn"; don't forget to get the nut style of your choice. Erthenvar carries these in the USA.
4 | LED3MM WHITE | LED3MM | LED3MM | 3MM White LED |  |  |  |  |  | https://www.taydaelectronics.com/leds/round-leds/3mm-leds/white/led-3mm-white-water-clear-ultra-bright.html | Forward Voltage(V): 3.2-3.4; Current(MA): 20; Luminous intensity(MCD): 14,000 - 16,000
4 | LED3MM YELLOW | LED3MM | LED3MM | 3MM Yellow LED |  |  |  |  |  | https://www.taydaelectronics.com/leds/round-leds/3mm-leds/yellow/led-3mm-yellow.html | Forward voltage(V): 2.0-2.3; Current(mA): 20; Luminous intensity(MCD): 2,000 - 3,000
1 | LM4040A10IDBZR | LM4041A12DBZ | DBZ_R-PDSO-G3 | 10V Reference |  |  | IC101 |  | 595-LM4040C10IDBZR
1 | MCP1703AT-5002E/CB | MCP1703CB | SOT23 | 5V Regulator |  |  | IC100 |  | 579-MCP1703AT5002ECB
1 | 470 | R-US_R0603 | R0603 | Resistor .1% |  |  | R101 |  | 660-RN731JTTD4700B25
8 | 10k | R-US_R0603 | R0603 | Resistor 1% | R1,R2,R3,R4,R5,R6,R7,R8 |  |  |  | 71-CRCW0603-10K-E3
8 | 120k | R-US_R0603 | R0603 | Resistor .1% |  |  | R100 | R13,R15,R18,R19,R21,R22,R23 | 71-TNPW0603120KBEEA
4 | 15k | R-US_R0603 | R0603 | Resistor .05% |  |  |  | R9,R10,R11,R12 | 667-ERA-3ARW153V
8 | 1k | R-US_R0603 | R0603 | Resistor .1% |  | R102,R103,R104,R105 |  | R14,R16,R17,R20 | 652-CRT0603BY1001EAS
1 | REF02AU | REF02AU | SOIC127P600X175-8N | 5V Voltage Reference |  |  | U100 |  | 595-REF02AU
1 | TEENSY3.1_ALL | TEENSY3.1_ALL | TEENSY3.1_ALL | Teensy 3.2
1 | OPA4171 | TL074D | SO14 | Op Amp |  |  |  | IC1 | 595-OPA4171AIDR

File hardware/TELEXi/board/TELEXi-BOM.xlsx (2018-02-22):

Qty | Value | Device | Package | Description | TopBottom | BottomTop | BottomBottom | OC_MOUSER | URL | Notes
2 | 0805L010 | 0805L010 | 0805L | Fuses |  |  | F100,F101 | 576-0805L010
2 | 1x03 MALE | 1x03M | 1X03M | 1x3 Header, Male |  |  |  |  |  | i2c Connectors; Standard Headers
2 | 1x06 FEMALE | 1x06F | 1X06F | 1x6 Header, Female |  |  |  |  |  | Board Interconnects; Safe to Substutite Machined Headers
2 | 1x06 MALE | 1x06M | 1X06M | 1x6 Header, Male |  |  |  |  |  | Board Interconnects; Safe to Substutite Machined Headers
2 | 1x14 FEMALE | 1x14F | 1X14F | 1x14 Header, Female |  |  |  |  |  | Teensy Interconnects; Safe to Substitute Machined Headers
2 | 1x14 MALE | 1x14M | 1X14M | 1x14 Header, Male |  |  |  |  |  | Teensy Interconnects; Safe to Substitute Machined Headers
1 | 2x03 MALE | 2x03M | 2x03M | 2x3 Header, Male |  |  |  |  |  | Jumpers; Standard Headers
1 | 2x05 MALE | 2x05M | 2x05M | 5x2 Europower, Male |  |  |  |  |  | Europower Connector
4 | ALPHA-9MMF2A | ALPHA-9MMF2A | EVUF | B10K Pot |  |  |  |  | https://www.thonk.co.uk/shop/alpha-9mm-pots-vertical-t18/ | B10K Linear Potentiometer; I use the T18 Shaft. Synthrotek also carries these in the USA
4 | Knobs & Caps | KNOB | Small Black Skirted | Selco Knob |  |  |  |  | https://www.thonk.co.uk/shop/intellijel-style-knobs/ | Small Black Skirted T18 Knob and Small Grey Caps
1 | BAS70-04 | BAS70-04 | SOT23 | Schottky Diodes |  |  | D100 | 771-BAS70-04-T/R
10 | .1u | CAP0603-CAP | 0603-CAP | Capacitor; >=16V; 5% | C100, C101, C102, C103 | C1,C2 | C105,C112,C113,C114 | 581-06033C104JAT2A
1 | .01u | CAP0603-CAP | 0603-CAP | Capacitor; >=16V; 10% |  | C3 |  | 80-C0603C103K5REAUTO
4 | 4,700p | CAP0603-CAP | 0603-CAP | Capacitor; >=16V; 5% |  |  | C104,C106,C107,C108 | 81-GRM1885C1H472JA1D
4 | 1u | CAP0603-CAP | 0603-CAP | Capacitor; >=16V; 10% |  | C4 | C111,C115,C116 | 581-06033C105KAT2A
2 | 10uf | CAP1206 | 1206-CAP | Capacitor; >=16V; 10% |  |  | C109,C110 | 81-GRM31CR71E106KA12
4 | EURO_JACKS-7 | EURO_JACKS-7 | WQP_PJ_301M | Thonkiconn 3.5mm |  |  |  |  | https://www.thonk.co.uk/shop/3-5mm-jacks/ | "Thonkiconn"; don't forget to get the nut style of your choice. Erthenvar carries these in the USA.
1 | LM4040A10IDBZR | LM4041A12DBZ | DBZ_R-PDSO-G3 | 10V Reference |  |  | IC100 | 595-LM4040C10IDBZR
1 | MCP1703CB | MCP1703CB | SOT23 | 5V Regulator |  |  | IC102 | 579-MCP1703AT5002ECB
8 | 200k | R-US_R0603 | R0603 | Resistor .1% | R100,R101,R102,R103 |  | R107,R109,R111,R112 | 667-ERA-3AEB204V
4 | 33k | R-US_R0603 | R0603 | Resistor .1% |  |  | R105, R106, R108, R110 | 667-ERA-3AEB333V
1 | 470 | R-US_R0603 | R0603 | Resistor .1% |  |  | R104 | 660-RN731JTTD4700B25
1 | TEENSY 3.2 | TEENSY 3.2 | TEENSY 3.2 | Teensy 3.2 |  |  |  |  | https://store.oshpark.com/products/teensy-3-1 | OSH Park has the best price on Teensy 3.2. Plus, they are purple which makes the TELEX sound better.
1 | MCP6004 | TL074D | SO14 | Op Amp |  |  | IC101 | 579-MCP6004T-I/SL

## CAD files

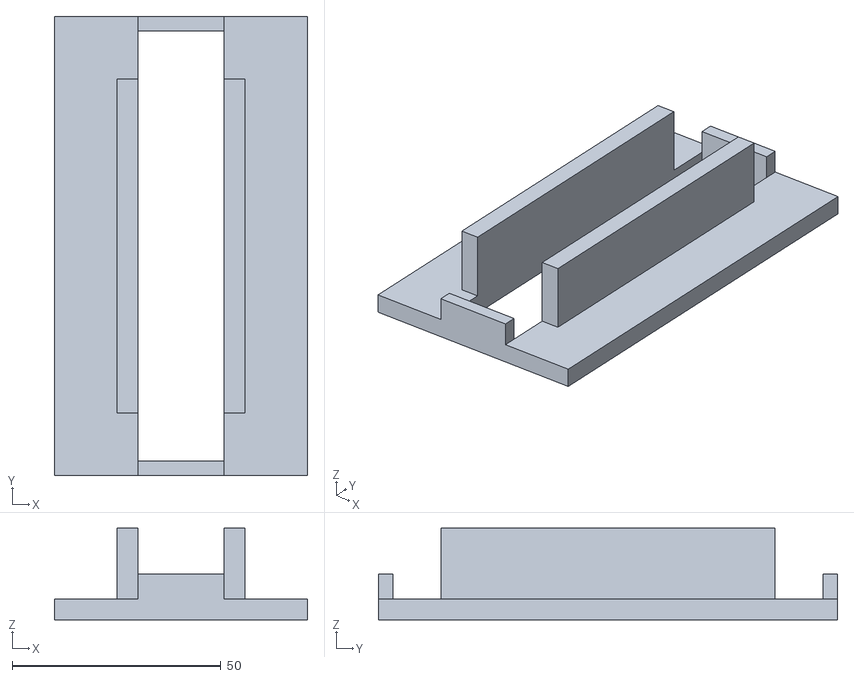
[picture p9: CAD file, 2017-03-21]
extras/assembly_frame.stl
60.6 x 110.0 x 22.0

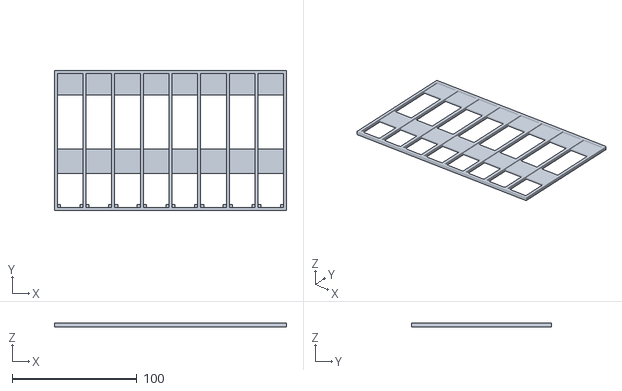
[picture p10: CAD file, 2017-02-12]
hardware/TELEXi/board/stencil_frame/txi_bottom_multi.stl
186.2 x 112.3 x 3.20

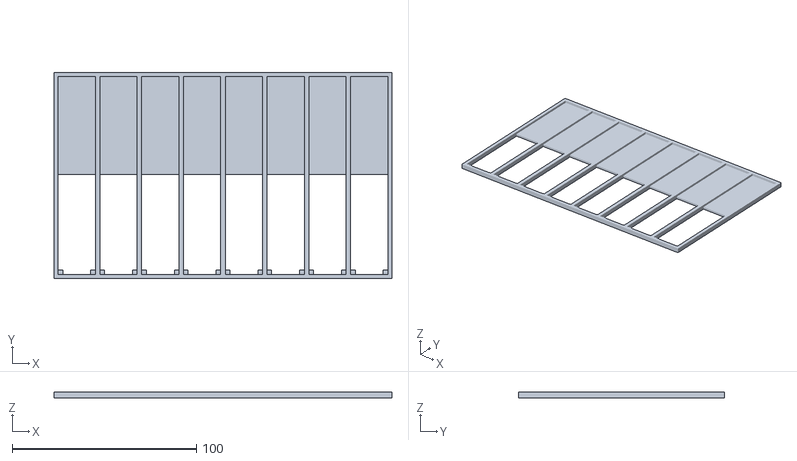
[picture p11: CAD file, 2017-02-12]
hardware/TELEXo/board/stencil_frame/txo_top_multi.stl
183.4 x 112.0 x 3.20

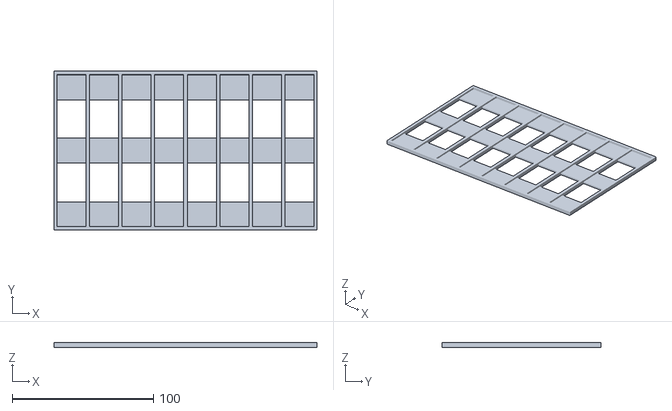
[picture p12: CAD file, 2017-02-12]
hardware/TELEXi/board/stencil_frame/txi_top_multi.stl
186.2 x 112.3 x 3.20

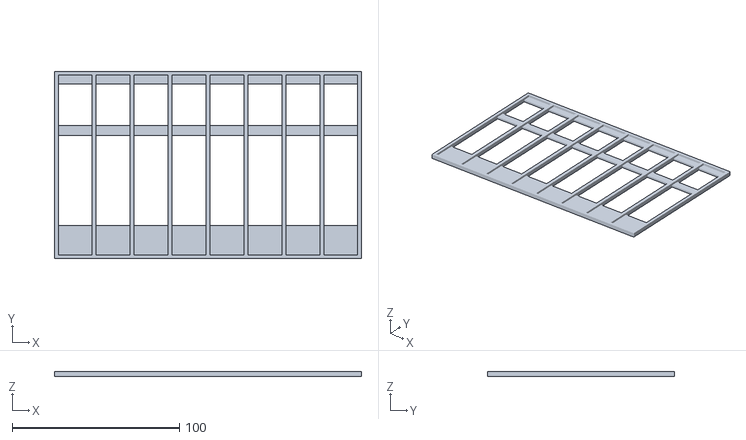
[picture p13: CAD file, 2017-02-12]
hardware/TELEXo/board/stencil_frame/txo_bottom_multi.stl
183.4 x 112.0 x 3.20

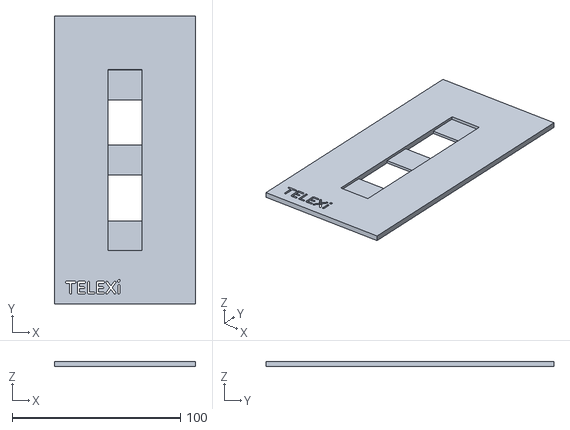
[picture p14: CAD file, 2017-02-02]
hardware/TELEXi/board/stencil_frame/telexi_generic.stl
84.0 x 171.3 x 3.20

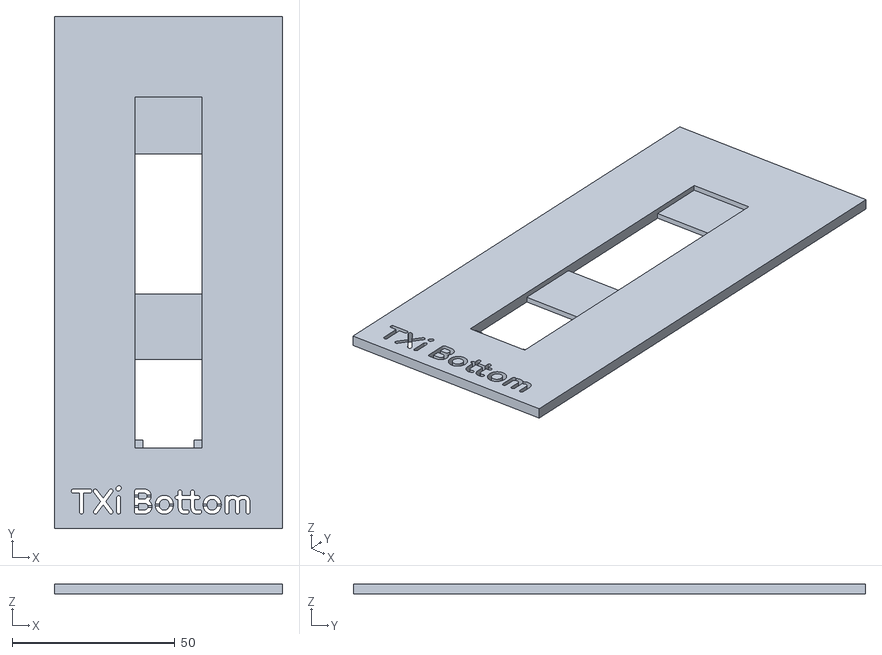
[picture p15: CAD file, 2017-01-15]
hardware/TELEXi/board/stencil_frame/txi.stl
70.0 x 157.3 x 3.20

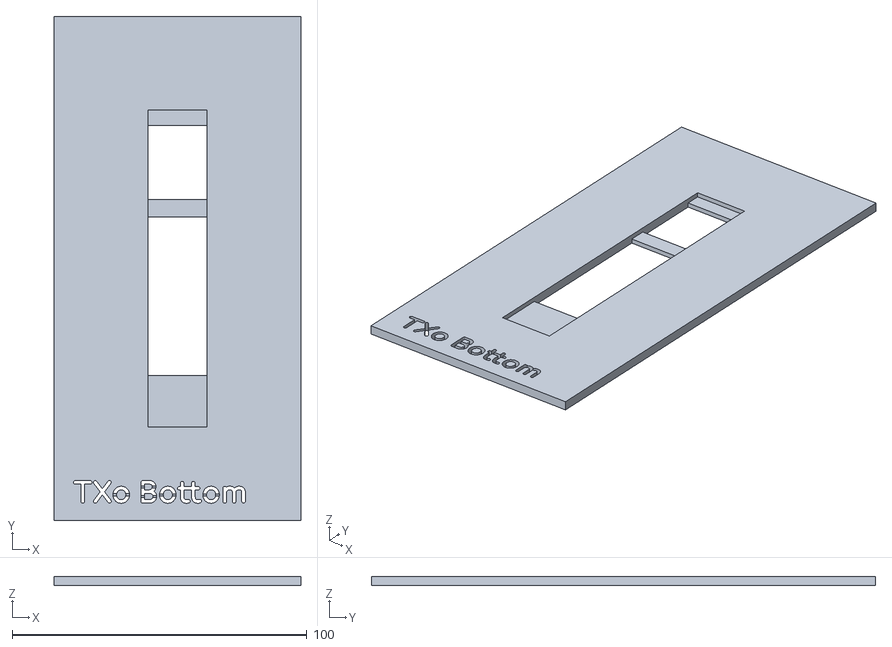
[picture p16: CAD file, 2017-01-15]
hardware/TELEXo/board/stencil_frame/txo_bottom.stl
83.7 x 171.0 x 3.20

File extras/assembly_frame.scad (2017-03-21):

smidge = .4;
smoodge = 1;

pcbX = 20.2 + smidge;
pcbY = 107.01 + smoodge;
pcbZ = 1.6;

depth = 25;

difference(){

    translate([0,0,5])
        cube([pcbX + 10, 80, 17]);
    translate([5, 0, 5])
        cube([pcbX,pcbY,25 * pcbZ]);
}

snip = pcbY - 5;
nerdel = (110 - snip) / 2;

nerdelheight = 6;

difference(){
    translate([-15,-15,0])
        cube([pcbX + 40,110,5]);
    translate([5, nerdel - 15, 0])
        cube([pcbX,snip,100]);
}

translate([5,-15,5])
    cube([pcbX,nerdel, nerdelheight]);
translate([5,95-nerdel,5])
    cube([pcbX,nerdel, nerdelheight]);

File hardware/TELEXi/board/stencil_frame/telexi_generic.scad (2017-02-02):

$fn = 50;

// TXo Bottom

tolerance = .5;

pcbX = 20.02;
pcbY = 107.32;
pcbZ = 1.6;

frame = 32;

barOneStart = 0;
barOneEnd = 18;

barTwoStart = pcbY / 2 - 9;
barTwoEnd = barTwoStart + 18;

barThreeStart = pcbY - 18;
barThreeEnd = 107.01 + (tolerance / 2);

corner = 2.5;

difference(){

    union(){
        difference() {
            translate([-frame, - frame, 0])
                cube([pcbX + 2 * frame, pcbY + 2 * frame, 2 * pcbZ]);
            translate([-tolerance/2, -tolerance/2, 0])
                cube([pcbX + tolerance, pcbY + tolerance, 2 * pcbZ]);
        }

        translate([-tolerance/2, barOneStart-(tolerance/2), 0])
            cube([pcbX + tolerance, barOneEnd - barOneStart -tolerance, pcbZ]);
            
        translate([-tolerance/2, barTwoStart, 0])
            cube([pcbX + tolerance, barTwoEnd - barTwoStart, pcbZ]);
        
        translate([-tolerance/2, barThreeStart, 0])
            cube([pcbX + tolerance, barThreeEnd - barThreeStart, pcbZ]);

    }

     translate([-frame * .8, -frame * .8]) {
       linear_extrude(height = 2 * pcbZ)
        text("TELEXi", font = "Core Humanist Sans:style=Bold", size = 8);
     }
 
 }

/*

translate([-13,-frame * .74,0])
    cube([10, pcbZ * .5, pcbZ / 3]);


translate([-4,-frame * .655,0])
    cube([8, pcbZ * .4, pcbZ / 3]);
 
translate([-4,-frame * .755,0])
    cube([7, pcbZ * .4, pcbZ / 3]);

translate([3,-frame * .74,0])
    cube([7, pcbZ * .4, pcbZ / 3]);
 
translate([18,-frame * .74,0])
    cube([7, pcbZ * .4, pcbZ / 3]);
 
 */               

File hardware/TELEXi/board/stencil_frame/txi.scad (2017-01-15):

$fn = 50;

// TXi

tolerance = .5;

pcbX = 20.02;
pcbY = 107.32;
pcbZ = 1.6;

frame = 25;

barOneStart = 27;
barOneEnd = 47;

barTwoStart = 90;
barTwoEnd = 108;

corner = 2.5;

difference(){

    union(){
        difference() {
            translate([-frame, - frame, 0])
                cube([pcbX + 2 * frame, pcbY + 2 * frame, 2 * pcbZ]);
            translate([-tolerance/2, -tolerance/2, 0])
                cube([pcbX + tolerance, pcbY + tolerance, 2 * pcbZ]);
        }

        translate([-tolerance/2, barOneStart, 0])
            cube([pcbX + tolerance, barOneEnd - barOneStart, pcbZ]);
            
        translate([-tolerance/2, barTwoStart, 0])
            cube([pcbX + tolerance, barTwoEnd - barTwoStart, pcbZ]);
        
        translate([-tolerance/2,-tolerance/2,0])
            cube([corner, corner, pcbZ]);

        translate([pcbX - corner + (tolerance / 2), -tolerance/2, 0])
            cube([corner, corner, pcbZ]);
    }

     translate([-frame * .8, -frame * .8]) {
       linear_extrude(height = 2 * pcbZ)
        text("TXi Bottom", font = "Core Humanist Sans:style=Bold", size = 8);
     }
 
 }


translate([-4,-frame * .61,0])
    cube([10, pcbZ * .4, pcbZ / 3]);
 
translate([-4,-frame * .74,0])
    cube([10, pcbZ * .4, pcbZ / 3]);

translate([5,-frame * .72,0])
    cube([7, pcbZ * .4, pcbZ / 3]);
 
translate([19.4,-frame * .72,0])
    cube([7, pcbZ * .4, pcbZ / 3]);

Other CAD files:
hardware/TELEXo/board/stencil_frame/txo_generic.stl
hardware/TELEXo/board/stencil_frame/txo_top.stl
hardware/TELEXi/board/stencil_frame/txi_bottom_multi.scad
hardware/TELEXi/board/stencil_frame/txi_top_multi.scad
hardware/TELEXo/board/stencil_frame/txo_bottom.scad
hardware/TELEXo/board/stencil_frame/txo_bottom_multi.scad
hardware/TELEXo/board/stencil_frame/txo_generic.scad
hardware/TELEXo/board/stencil_frame/txo_top.scad

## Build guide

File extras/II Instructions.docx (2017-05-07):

Connecting TELEX to your Teletype via the II Bus

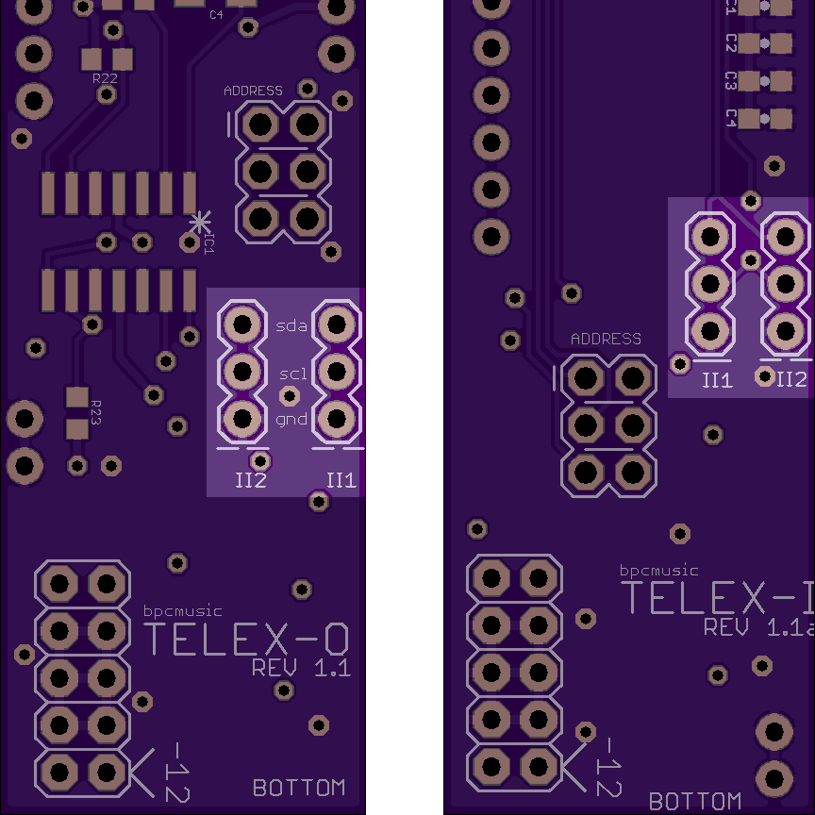
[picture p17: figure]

The II bus consists of three signals: GND, SCL and SDA. We have included a three-conductor jumper wire with your module to facilitate their connection to the II bus. This is a little different than the ribbon connector and 2x3 connector that is shipped with the Teletype. You can use either one – but there are important considerations you need to keep in mind:

- On the Teletype and Trilogy Modules, the II pins are oriented top to bottom (ground on the top).
- On the TELEX modules and Ansible, these pins are oriented bottom to top (ground on the bottom).
- On the TELEX modules, the vertical columns of II pins are slightly separated (2x3 connectors won’t cover both columns – they are designed for jumpers).

Ensure that you are appropriately orienting your ground wire when connecting the devices together. The rule is “Twist to the Teletype or Trilogy” - if you need a mnemonic.

Each of the TELEX modules has two columns of II pins that are separated slightly. This allows you to use the included jumper cables to daisy-chain from one module to another. The diagrams below illustrate where the pins are located on the two modules. The white lines below the columns on the PCB designate the locations of the ground wire.

TELEX Addendum 20170107-091371c

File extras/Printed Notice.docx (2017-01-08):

NOTICE

The trace has been rudely cut on your Teensy. It no longer can be powered by the external USB connection.

This allows you to have your module powered by the Eurorack power supply while simultaneously debugging using a serial USB connection. We have indicated this by the red stripe that was unprofessionally painted on the Teensy’s processor.

To upgrade your module’s firmware over USB, the Eurorack power supply will need to be connected and powered on. Enjoy the hassle and have a nice day.

TELEX Addendum 2017017-091371b

WARNING

DO NOT connect your module’s Teensy processor to USB while it is connected to Eurorack power. This will cause bad things to happen. Chernobyl-style bad things. Resist the temptation.

To upgrade your firmware, disconnect your module or simply remove the Teensy from the back of the module and connect it to your computer. Follow the procedure for loading firmware onto the Teensy that is appropriate for your operating system.

If you wish to debug the module via USB, you will need to separate VIN from VUSB on the underside of the Teensy. This is a simple procedure that should be done carefully to ensure that you don’t damage your Teensy, module, computer, or fabric of the universe.

TELEX Addendum 2017017-091371c

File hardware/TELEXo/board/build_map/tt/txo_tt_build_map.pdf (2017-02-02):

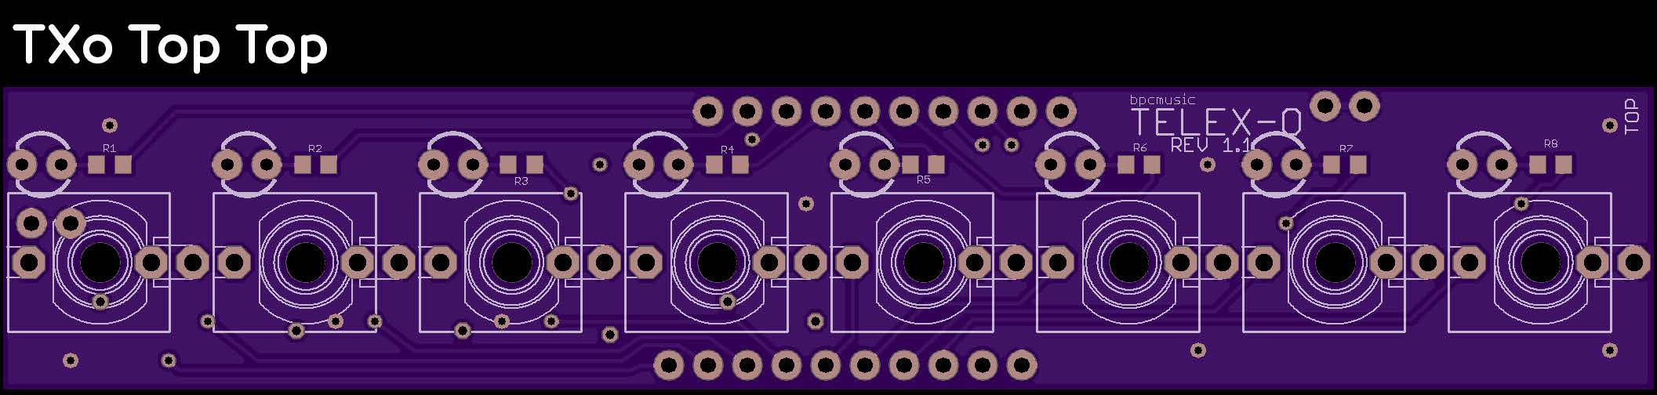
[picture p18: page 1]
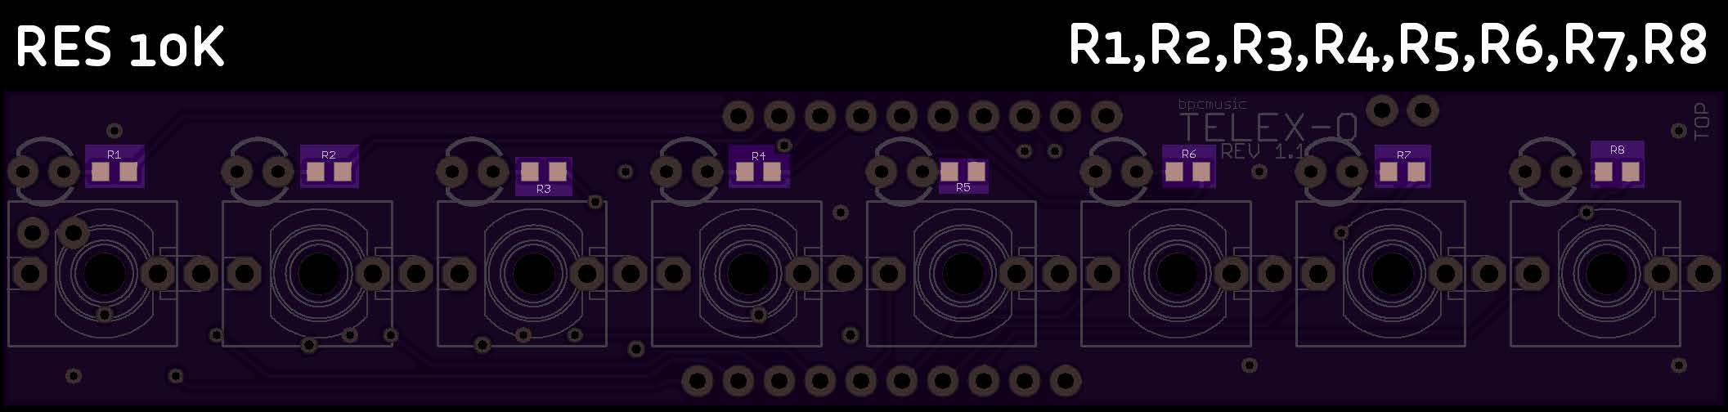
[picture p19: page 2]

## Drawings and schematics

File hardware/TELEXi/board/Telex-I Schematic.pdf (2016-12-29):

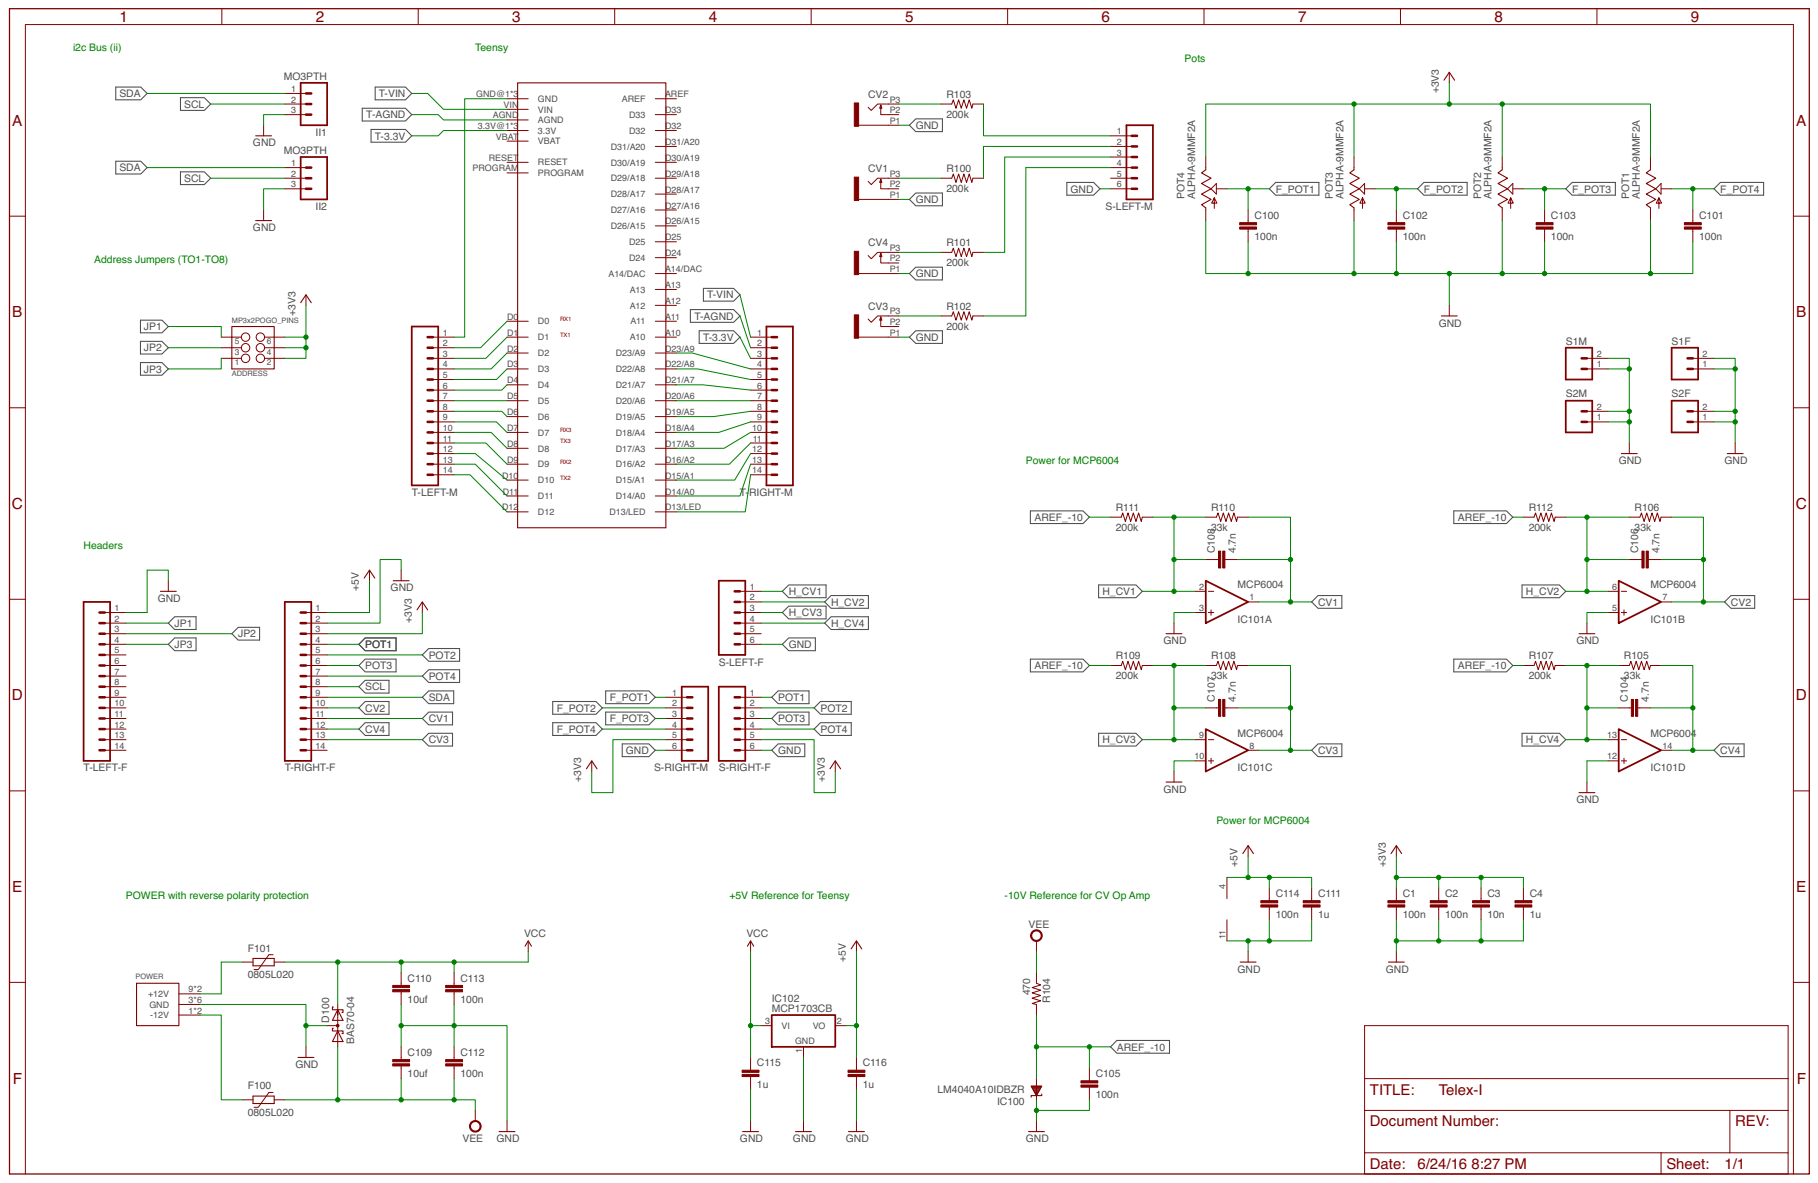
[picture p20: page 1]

POWER with reverse polarity protection

Document Number: | REV:

Date: 6/24/16 8:27 PM | Sheet: 1/1

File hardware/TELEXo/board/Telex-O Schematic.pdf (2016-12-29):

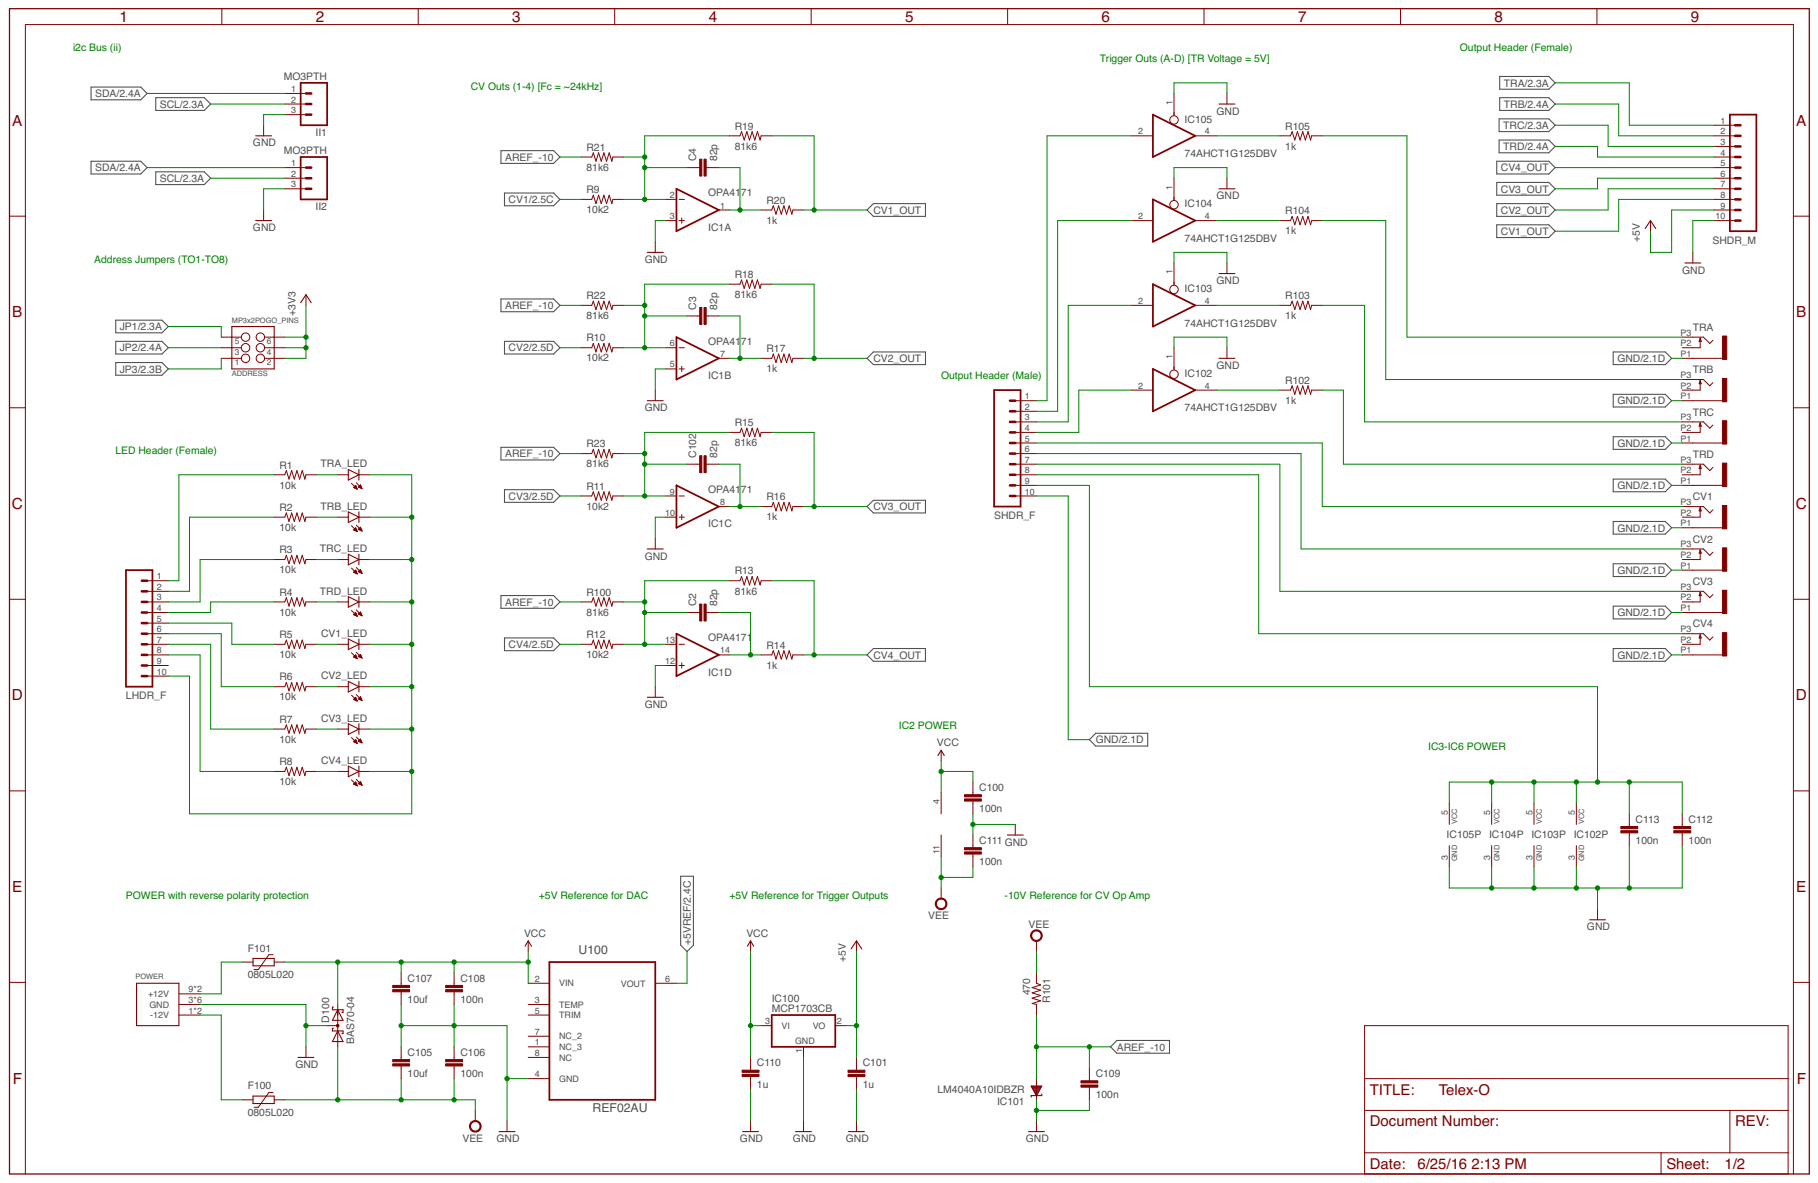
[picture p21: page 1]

Trigger Outs (A-D) [TR Voltage = 5V]

POWER with reverse polarity protection

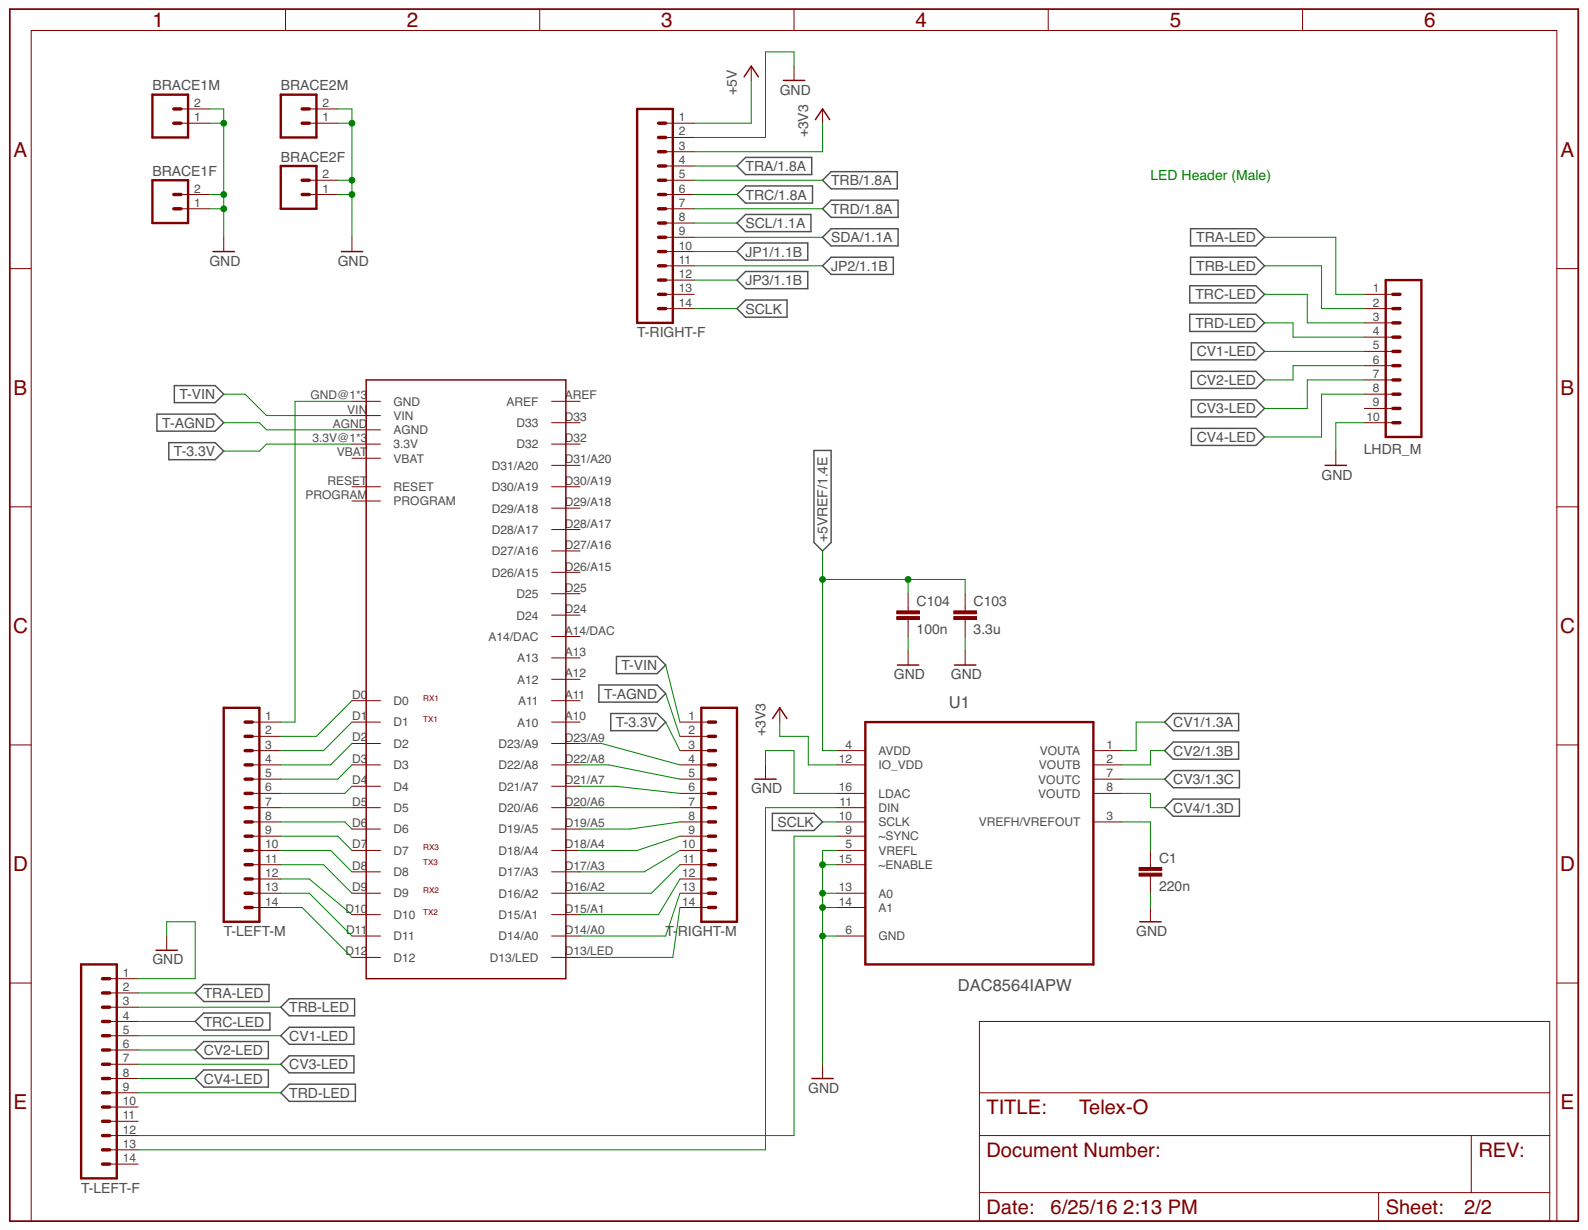
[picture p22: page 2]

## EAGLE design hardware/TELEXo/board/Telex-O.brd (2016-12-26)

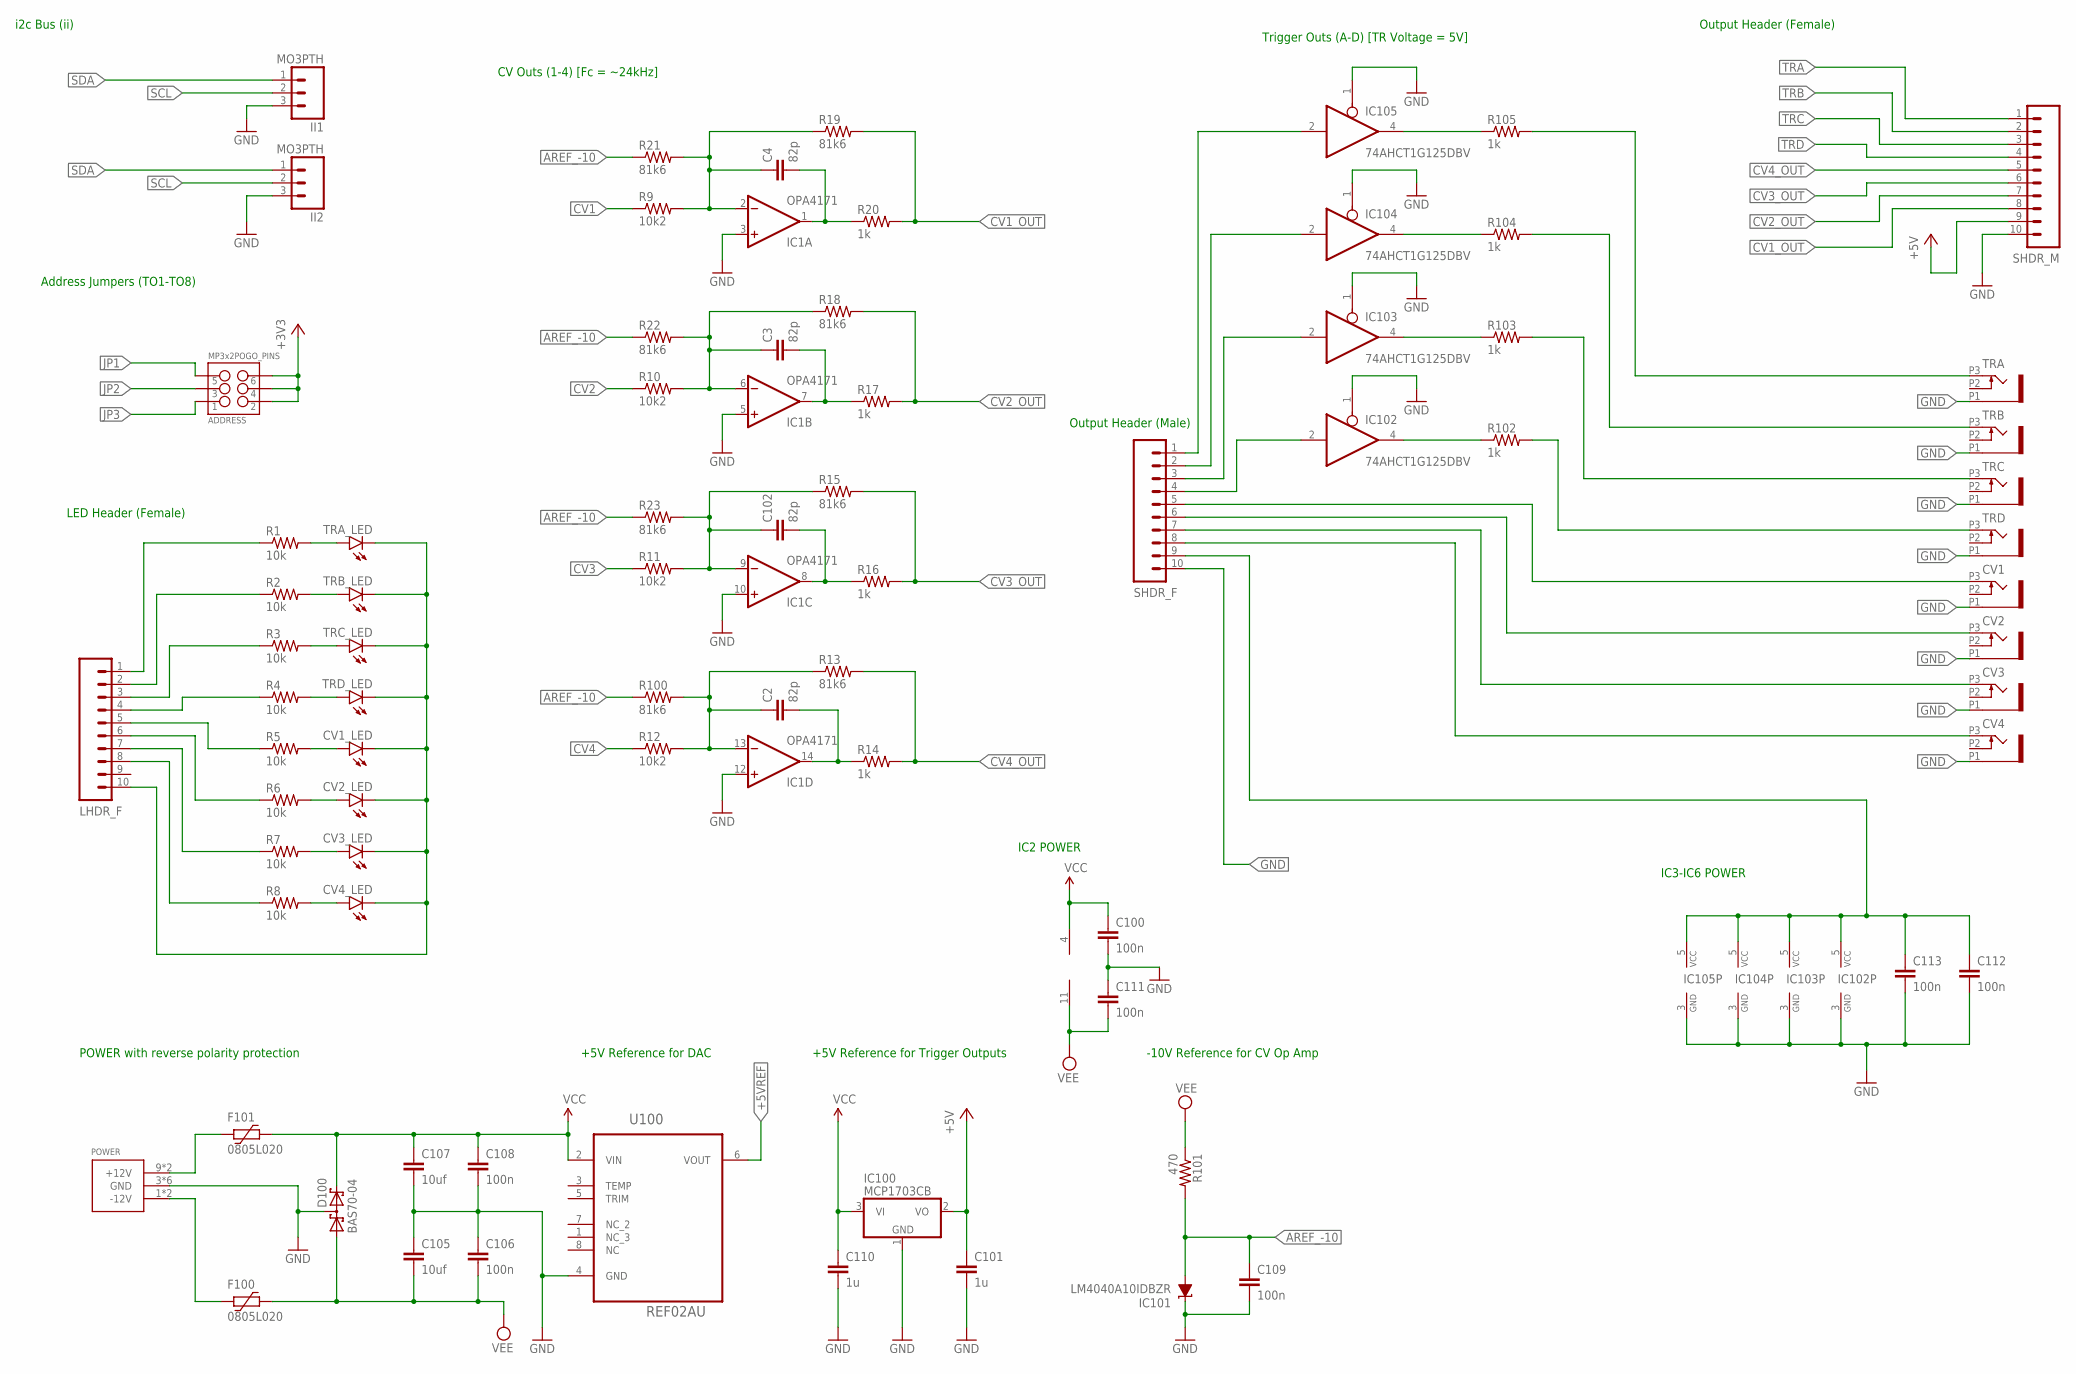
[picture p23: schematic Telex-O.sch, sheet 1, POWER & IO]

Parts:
ADDRESS: MP3x2POGO_PINS; 2X3_POGO
C2, C3, C4, C102: 82p; 1206
C100, C106, C108, C109, C111, C112, C113: 100n; 0603-CAP
C101, C110: 1u; 0603-CAP
C105, C107: 10uf; 1206
CV1, CV2, CV3, CV4: EURO_JACKS-7; WQP_PJ_301M
CV1_LED, CV2_LED, CV3_LED, CV4_LED: LED3MM
D100: BAS70-04; SOT23
F100, F101: 0805L020; 0805L
IC1: OPA4171; SO14
IC100: MCP1703CB; SOT23
IC101: LM4040A10IDBZR; DBZ_R-PDSO-G3
IC102, IC103, IC104, IC105: 74AHCT1G125DBV; SOT23-5
II1, II2: MO3PTH; 1X03
LHDR_F: M10SILK_FEMALE_PTH; 1X10
POWER: 10-Pin; POWER_10
R1, R2, R3, R4, R5, R6, R7, R8: 10k; R0603
R9, R10, R11, R12: 10k2; R0603
R13, R15, R18, R19, R21, R22, R23, R100: 81k6; R0603
R14, R16, R17, R20, R102, R103, R104, R105: 1k; R0603
R101: 470; R0603
SHDR_F: M10SILK_FEMALE_PTH; 1X10
SHDR_M: M10SILK_FEMALE_PTH; 1X10
TRA: EURO_JACKS-7; WQP_PJ_301M
TRA_LED: LED3MM
TRB: EURO_JACKS-7; WQP_PJ_301M
TRB_LED: LED3MM
TRC: EURO_JACKS-7; WQP_PJ_301M
TRC_LED: LED3MM
TRD: EURO_JACKS-7; WQP_PJ_301M
TRD_LED: LED3MM
U100: REF02AU; SOIC127P600X175-8N

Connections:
+3V3: ADDRESS.P$2 (2), ADDRESS.P$4 (4), ADDRESS.P$6 (6); also elsewhere on the board
+5V: C101.1, IC100.2 (VO), SHDR_M.9; also elsewhere on the board
+5VREF: U100.6 (VOUT); also elsewhere on the board
AREF_-10: C109.1, IC101.2 (A), R21.1, R22.1, R23.1, R100.1, R101.2
CV1: R9.1; also elsewhere on the board
CV1_OUT: R19.2, R20.2, SHDR_M.8
CV2: R10.1; also elsewhere on the board
CV2_OUT: R17.2, R18.2, SHDR_M.7
CV3: R11.1; also elsewhere on the board
CV3_OUT: R15.2, R16.2, SHDR_M.6
CV4: R12.1; also elsewhere on the board
CV4_OUT: R13.2, R14.2, SHDR_M.5
GND: C100.2, C101.2, C105.1, C106.1, C107.2, C108.2, C109.2, C110.2, C111.1, C112.2, C113.2, CV1.P1 (1), CV1_LED.K (C), CV2.P1 (1), CV2_LED.K (C), CV3.P1 (1), CV3_LED.K (C), CV4.P1 (1), CV4_LED.K (C), D100.3 (C1A2), IC1.3 (+IN), IC1.5 (+IN), IC1.10 (+IN), IC1.12 (+IN), IC100.1 (GND), IC101.1 (C), IC102.1 (OE), IC102.3 (GND), IC103.1 (OE), IC103.3 (GND), IC104.1 (OE), IC104.3 (GND), IC105.1 (OE), IC105.3 (GND), II1.3, II2.3, LHDR_F.10, POWER.3 (GND), POWER.4 (GND), POWER.5 (GND), POWER.6 (GND), POWER.7 (GND), POWER.8 (GND), SHDR_F.10, SHDR_M.10, TRA.P1 (1), TRA_LED.K (C), TRB.P1 (1), TRB_LED.K (C), TRC.P1 (1), TRC_LED.K (C), TRD.P1 (1), TRD_LED.K (C), U100.4 (GND); also elsewhere on the board
JP1: ADDRESS.P$5 (5); also elsewhere on the board
JP2: ADDRESS.P$3 (3); also elsewhere on the board
JP3: ADDRESS.P$1 (1); also elsewhere on the board
M$22: C4.1, IC1.2 (-IN), R9.2, R19.1, R21.2
unnamed: F101.2, POWER.9 (+12V), POWER.10 (+12V)
unnamed: F100.2, POWER.1 (-12V), POWER.2 (-12V)
unnamed: CV4_LED.A, R8.2
unnamed: IC105.2 (I), SHDR_F.1
unnamed: CV3_LED.A, R7.2
unnamed: CV2_LED.A, R6.2
unnamed: CV1_LED.A, R5.2
unnamed: R4.2, TRD_LED.A
unnamed: R3.2, TRC_LED.A
unnamed: R2.2, TRB_LED.A
unnamed: R1.2, TRA_LED.A
unnamed: IC104.2 (I), SHDR_F.2
unnamed: IC103.2 (I), SHDR_F.3
unnamed: C4.2, IC1.1 (OUT), R20.1
unnamed: IC102.2 (I), SHDR_F.4
unnamed: C3.2, IC1.7 (OUT), R17.1
unnamed: C3.1, IC1.6 (-IN), R10.2, R18.1, R22.2
unnamed: R102.2, TRD.P3 (3)
unnamed: R103.2, TRC.P3 (3)
unnamed: C102.2, IC1.8 (OUT), R16.1
unnamed: C102.1, IC1.9 (-IN), R11.2, R15.1, R23.2
unnamed: LHDR_F.1, R1.1
unnamed: C2.2, IC1.14 (OUT), R14.1
unnamed: C2.1, IC1.13 (-IN), R12.2, R13.1, R100.2
unnamed: LHDR_F.2, R2.1
unnamed: LHDR_F.3, R3.1
unnamed: LHDR_F.4, R4.1
unnamed: IC102.4 (O), R102.1
unnamed: IC103.4 (O), R103.1
unnamed: IC104.4 (O), R104.1
unnamed: IC105.4 (O), R105.1
unnamed: R104.2, TRB.P3 (3)
unnamed: R105.2, TRA.P3 (3)
unnamed: C112.1, C113.1, IC102.5 (VCC), IC103.5 (VCC), IC104.5 (VCC), IC105.5 (VCC), SHDR_F.9
unnamed: CV3.P3 (3), SHDR_F.7
unnamed: LHDR_F.5, R5.1
unnamed: LHDR_F.6, R6.1
unnamed: LHDR_F.7, R7.1
unnamed: LHDR_F.8, R8.1
unnamed: CV1.P3 (3), SHDR_F.5
unnamed: CV2.P3 (3), SHDR_F.6
unnamed: CV4.P3 (3), SHDR_F.8
SCL: II1.2, II2.2; also elsewhere on the board
SDA: II1.1, II2.1; also elsewhere on the board
TRA: SHDR_M.1; also elsewhere on the board
TRB: SHDR_M.2; also elsewhere on the board
TRC: SHDR_M.3; also elsewhere on the board
TRD: SHDR_M.4; also elsewhere on the board
VCC: C100.1, C107.1, C108.1, C110.1, D100.2 (C2), F101.1, IC1.4 (V+), IC100.3 (VI), U100.2 (VIN)
VEE: C105.2, C106.2, C111.2, D100.1 (A1), F100.1, IC1.11 (V-), R101.1

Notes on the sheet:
POWER with reverse polarity protection
i2c Bus (ii)
LED Header (Female)
Address Jumpers (TO1-TO8)
CV Outs (1-4) [Fc = ~24kHz]
Trigger Outs (A-D) [TR Voltage = 5V]
IC2 POWER
IC3-IC6 POWER
Output Header (Male)
Output Header (Female)
+5V Reference for DAC
+5V Reference for Trigger Outputs
-10V Reference for CV Op Amp

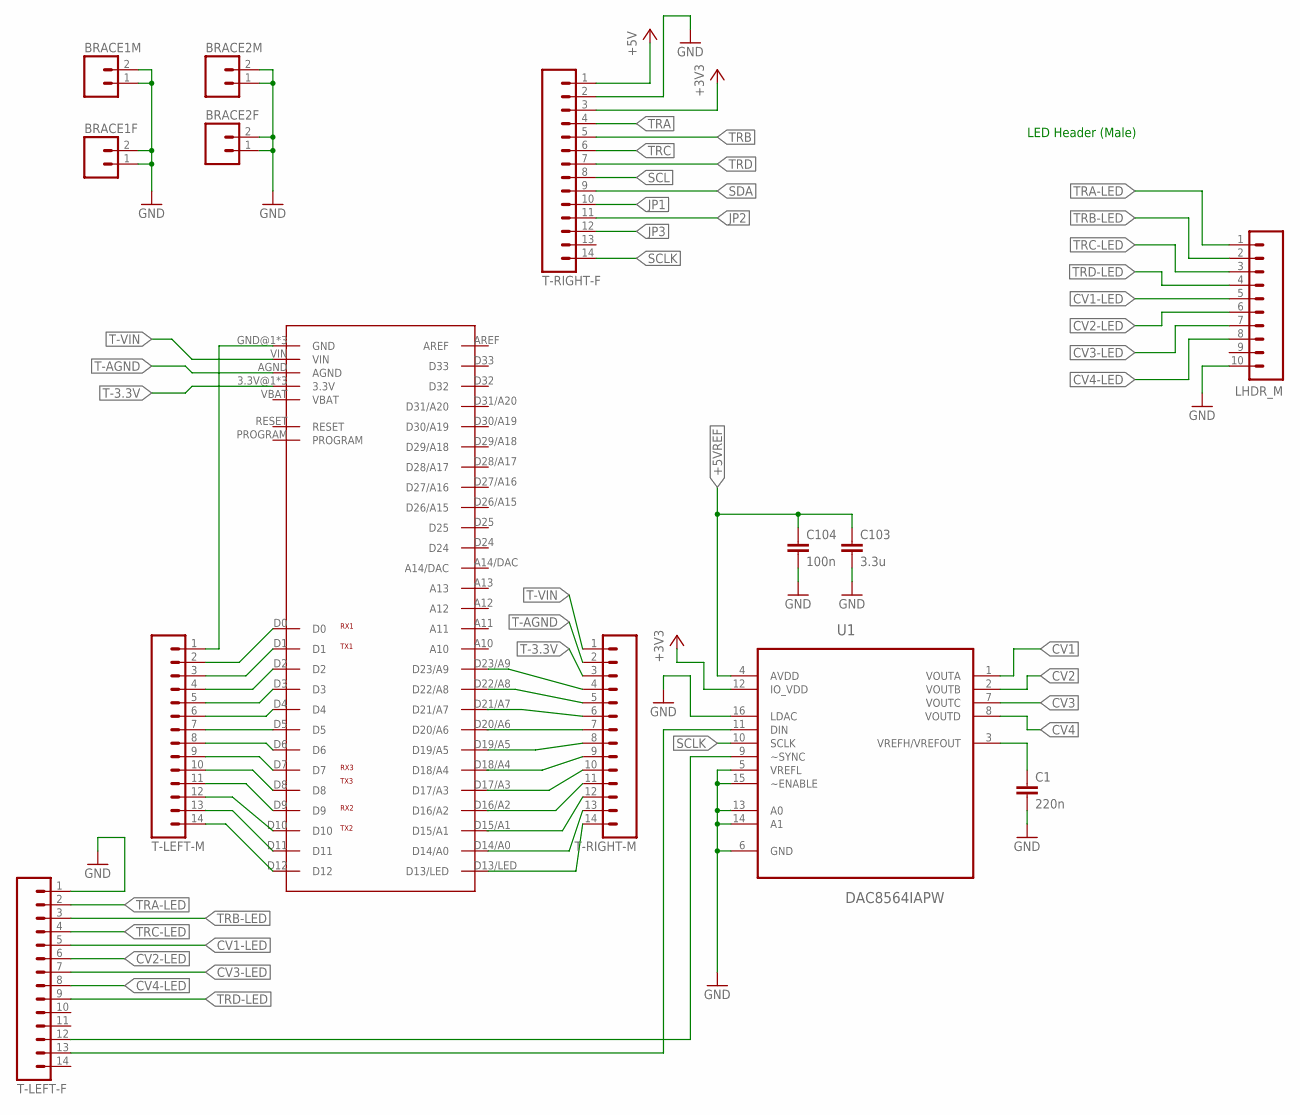
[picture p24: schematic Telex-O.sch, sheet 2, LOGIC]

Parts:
BRACE1F, BRACE1M, BRACE2F, BRACE2M: M02PTH; 1X02
C1: 220n; 0603-CAP
C103: 3.3u; 1206
C104: 100n; 0603-CAP
LHDR_M: M10SILK_FEMALE_PTH; 1X10
T-LEFT-F: M14; 1X14
T-LEFT-M: M14; 1X14
T-RIGHT-F: M14; 1X14
T-RIGHT-M: M14; 1X14
U1: DAC8564IAPW; SOP65P640X120-16N
U$1: TEENSY3.1_ALL

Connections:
+3V3: T-RIGHT-F.3, U1.12 (IO_VDD); also elsewhere on the board
+5V: T-RIGHT-F.1; also elsewhere on the board
+5VREF: C103.1, C104.1, U1.4 (AVDD); also elsewhere on the board
CV1: U1.1 (VOUTA); also elsewhere on the board
CV1-LED: LHDR_M.5, T-LEFT-F.5
CV2: U1.2 (VOUTB); also elsewhere on the board
CV2-LED: LHDR_M.6, T-LEFT-F.6
CV3: U1.7 (VOUTC); also elsewhere on the board
CV3-LED: LHDR_M.7, T-LEFT-F.7
CV4: U1.8 (VOUTD); also elsewhere on the board
CV4-LED: LHDR_M.8, T-LEFT-F.8
GND: BRACE1F.1, BRACE1F.2, BRACE1M.1, BRACE1M.2, BRACE2F.1, BRACE2F.2, BRACE2M.1, BRACE2M.2, C1.2, C103.2, C104.2, LHDR_M.10, T-LEFT-F.1, T-RIGHT-F.2, U1.5 (VREFL), U1.6 (GND), U1.13 (A0), U1.14 (A1), U1.15 (~ENABLE), U1.16 (LDAC); also elsewhere on the board
JP1: T-RIGHT-F.10; also elsewhere on the board
JP2: T-RIGHT-F.11; also elsewhere on the board
JP3: T-RIGHT-F.12; also elsewhere on the board
unnamed: T-RIGHT-M.14, U$1.D13/LED
unnamed: T-LEFT-F.12, U1.9 (~SYNC)
unnamed: T-LEFT-F.13, U1.11 (DIN)
unnamed: C1.1, U1.3 (VREFH/VREFOUT)
unnamed: T-LEFT-M.2, U$1.D0
unnamed: T-LEFT-M.3, U$1.D1
unnamed: T-LEFT-M.4, U$1.D2
unnamed: T-LEFT-M.5, U$1.D3
unnamed: T-LEFT-M.6, U$1.D4
unnamed: T-LEFT-M.7, U$1.D5
unnamed: T-LEFT-M.8, U$1.D6
unnamed: T-LEFT-M.9, U$1.D7
unnamed: T-LEFT-M.12, U$1.D10
unnamed: T-LEFT-M.13, U$1.D11
unnamed: T-LEFT-M.1, U$1.GND@1 (GND), U$1.GND@2 (GND), U$1.GND@3 (GND)
unnamed: T-LEFT-M.10, U$1.D8
unnamed: T-LEFT-M.11, U$1.D9
unnamed: T-LEFT-M.14, U$1.D12
unnamed: T-RIGHT-M.13, U$1.D14/A0
unnamed: T-RIGHT-M.8, U$1.D19/A5
unnamed: T-RIGHT-M.5, U$1.D22/A8
unnamed: T-RIGHT-M.4, U$1.D23/A9
SCL: T-RIGHT-F.8; also elsewhere on the board
SCLK: T-RIGHT-F.14, U1.10 (SCLK)
SDA: T-RIGHT-F.9; also elsewhere on the board
T-3.3V: T-RIGHT-M.3, U$1.3.3V@1 (3.3V), U$1.3.3V@2 (3.3V), U$1.3.3V@3 (3.3V)
T-AGND: T-RIGHT-M.2, U$1.AGND
T-VIN: T-RIGHT-M.1, U$1.VIN
TRA: T-RIGHT-F.4; also elsewhere on the board
TRA-LED: LHDR_M.1, T-LEFT-F.2
TRB: T-RIGHT-F.5; also elsewhere on the board
TRB-LED: LHDR_M.2, T-LEFT-F.3
TRC: T-RIGHT-F.6; also elsewhere on the board
TRC-LED: LHDR_M.3, T-LEFT-F.4
TRD: T-RIGHT-F.7; also elsewhere on the board
TRD-LED: LHDR_M.4, T-LEFT-F.9

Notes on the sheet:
LED Header (Male)

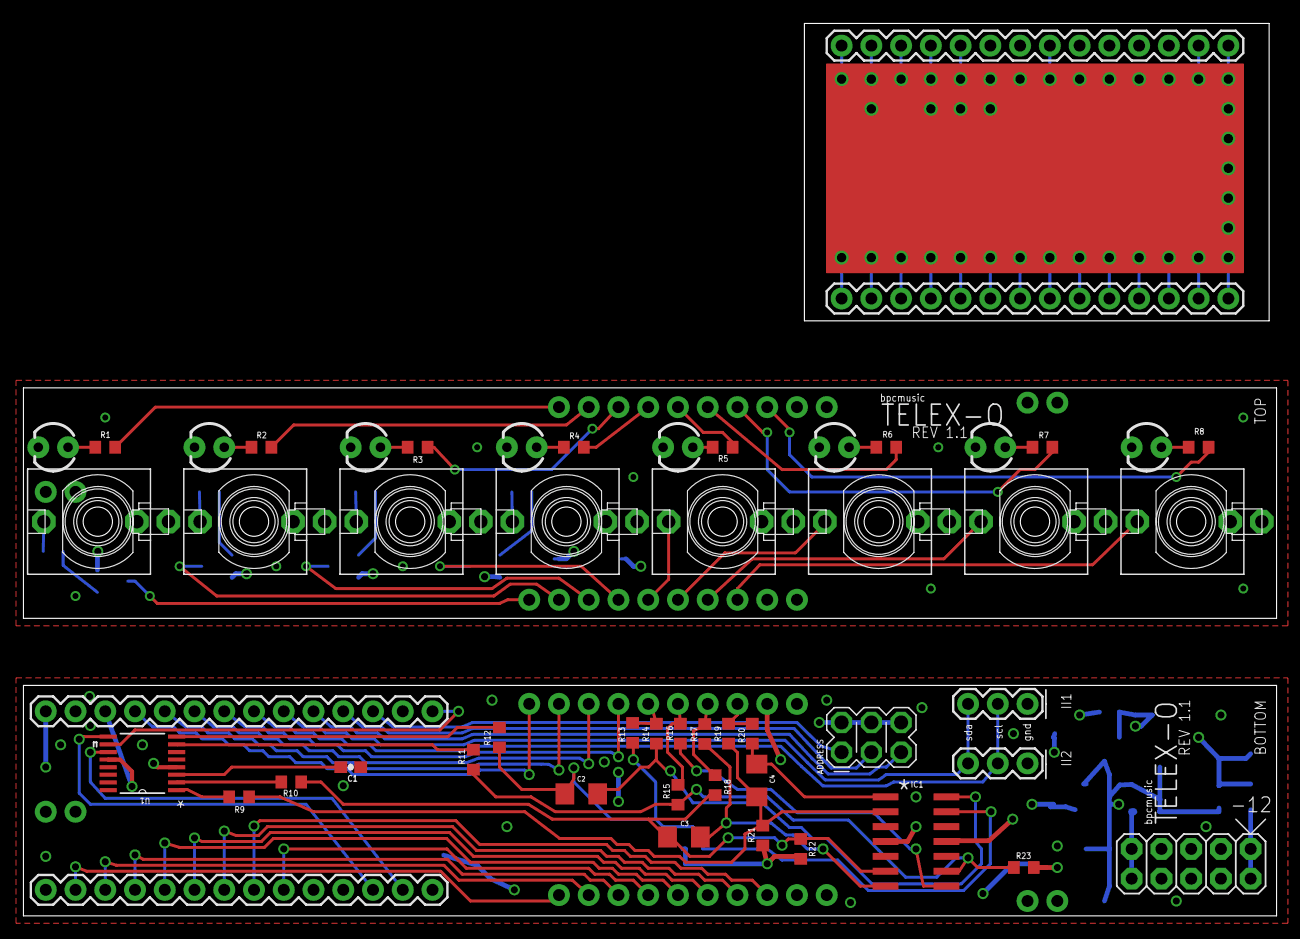
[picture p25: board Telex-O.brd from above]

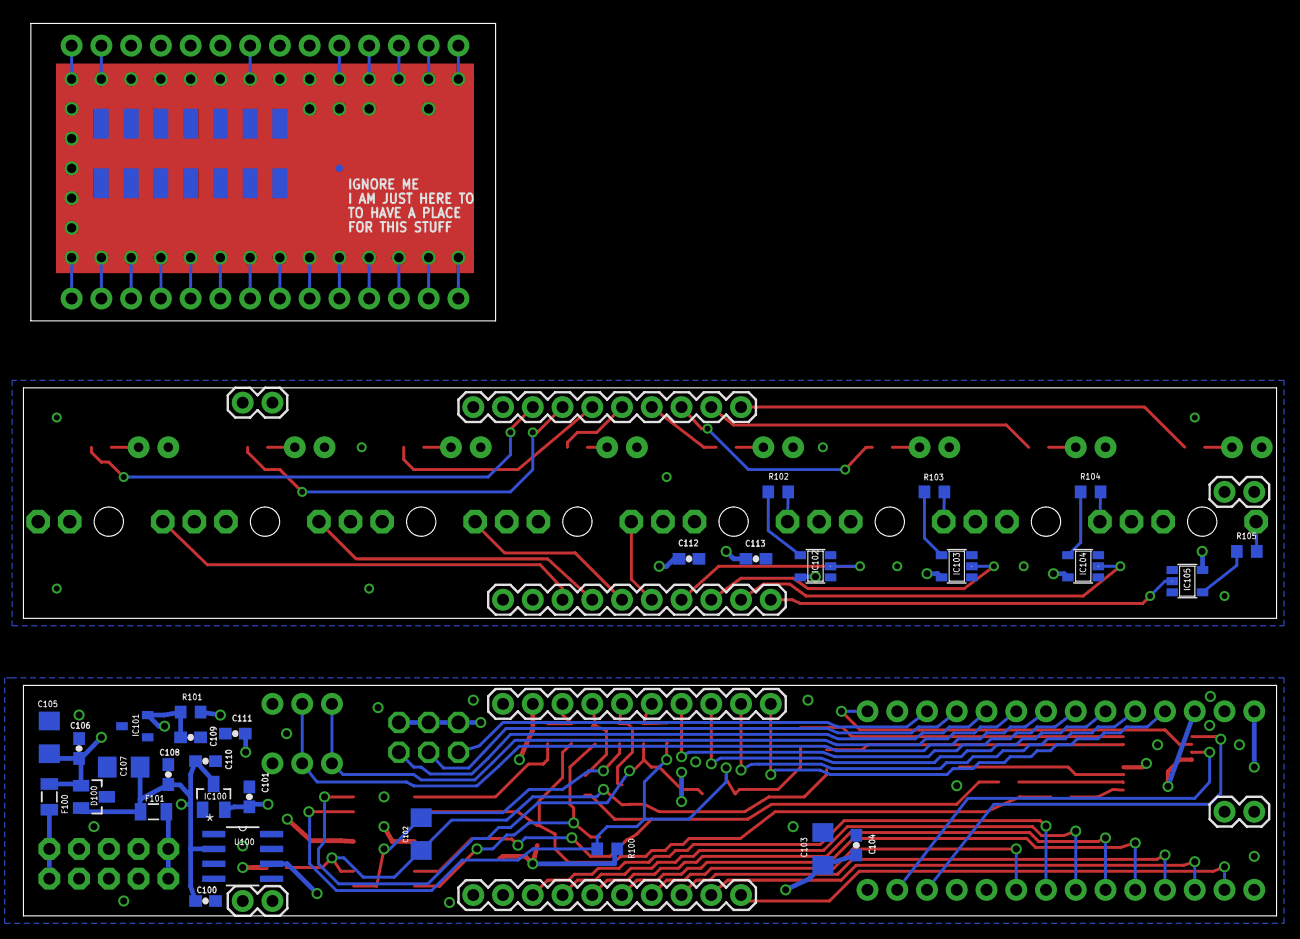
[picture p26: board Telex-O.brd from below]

Board: 4 copper layers, 107.0 x 76.2 mm, 92 parts (38 on the bottom side), 101 nets.

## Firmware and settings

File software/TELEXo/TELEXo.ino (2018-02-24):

/*
 * TELEXo Eurorack Module
 * (c) 2016-2018 Brendon Cassidy
 * MIT License
 */

// defined globals shared across the app
#include "defines.h"

// i2c Wire Library (for Teensy)
#include <i2c_t3.h>

// eeprom library
#include <EEPROM.h>

// DAC stuff
#include <SPI.h>
#include "DAC7565.h"

// support libraries
#include "telex.h"
#include "TriggerOutput.h"
#include "CVOutput.h"
#include "TxHelper.h"

/*
 * Ugly Globals
 */

// i2c pullup setting
bool enablePullups = false;

// config inputs
int configPins[] = { 15, 16, 17 };
int configID = TO;

// write timer and its local variables
IntervalTimer writeTimer;
int readerTemp = 0;
int p = 0;

// CV Outputs
DAC dac(-1, 10, -1, 11, 13);
int dacOutputs[] = { DAC_CHANNEL_D, DAC_CHANNEL_C, DAC_CHANNEL_B, DAC_CHANNEL_A };
int pwmLedPins[] = { 3, 4, 5, 6 };
CVOutput *cvOutputs[4];
int writeRate = 100;

// Trigger Outputs
int trLedPins[] = { 0, 1, 2, 7 };
int trPins[] = { 23, 22, 21, 20 };
TriggerOutput *triggerOutputs[4];

// target output
int targetOutput = 0;

// iterator values
int i = 0;
int q = 0;

// timing loop
unsigned long currentTime;
unsigned long nextTime;
unsigned long dacTime;
unsigned long kTime;

#ifdef DEBUG
// led status for tx/rx
int LED = 13;
unsigned long ledInterval;
bool ledOn = false;
// clocking variables
volatile unsigned long n = 0;
unsigned long l = 0;
unsigned long t = 0;
float persec = 0;
#endif

bool dacOn = true;

/*
 * Setup Function 
 */
void setup() {
  
  // config
  int cfg = 0;
  for (i=0; i < 3; i++){
    pinMode(configPins[i], INPUT);
    // can't do a digital read cuz some idiot had the pins floating
    // needed to do this cuz of the dumb way i designed the board
    // embarassing to have this be one of the first things in the code
    // (hiding my head in shame)
    int cRead = analogRead(configPins[i]) > 1000 ? 1 : 0;
    cfg += cRead << i;
  }
  configID += cfg;  
  
  writeRate = 1000000 / SAMPLINGRATE;

#ifdef DEBUG
  delay(225);
  // set the behind-the-scenes LED output pin
  pinMode(LED, OUTPUT);
  // turn on serial
  Serial.begin(250000);
  // wait for debugging connection   
  while (!Serial);
  // kick off the logging
  t = millis() + LOGINTERVAL;
  Serial.printf("NOW: %d\n", millis());
  Serial.printf("ConfigID: %d\n", configID);
#endif
    
  // initialize the DAC
  if (dacOn) {
    dac.init();
    dac.setReference(DAC_REFERENCE_ALWAYS_POWERED_UP);
    dac.writeChannel(DAC_CHANNEL_ALL, DAC_MAX_SCALE / 2);  
  }
  
  // initialize the outputs
  for (i=0; i < 4; i++) {
    // set up the trigger and cv outputs
    triggerOutputs[i] = new TriggerOutput(trPins[i], trLedPins[i]);
    cvOutputs[i] = new CVOutput(dacOutputs[i], pwmLedPins[i], dac);
    cvOutputs[i]->ReferenceTriggers(triggerOutputs, sizeof(triggerOutputs));
  }

  // read the calibration data
  readCalibrationData();

  // start the write timer
  writeTimer.begin(writeOutputs, writeRate);
  kTime = millis() + LEDRATE;

  // initialize the teensy optimized wire library
  Wire.begin(I2C_SLAVE, configID, I2C_PINS_18_19, enablePullups ? I2C_PULLUP_INT : I2C_PULLUP_EXT, I2C_RATE_400); // I2C_RATE_2400
  Wire.onReceive(receiveEvent);
  
}

/*
 * Main Arduino Appliation Loop
 */
void loop() {

  currentTime = millis();

  // update the TRIGGERS
  for (i=0; i< 4; i++){
    // update the triggers
    triggerOutputs[i]->Update(currentTime);
  } 

  // update the CV LEDs
  if (currentTime >= kTime){
    for (i = 0; i < 4; i++)
      cvOutputs[i]->UpdateLED();
    kTime = currentTime + LEDRATE;
  }

#ifdef DEBUG
    // flash the back LED and log the timing
    if (currentTime >= t){
      noInterrupts();
      l = n;
      n = 0;
      interrupts();
      t = currentTime + LOGINTERVAL;
      persec = l / 10.;
      Serial.printf("per sec: %f\n", persec);    
    }  
    // turn off activity LED
    if (ledOn && currentTime > ledInterval) {
      ledOn = false;
      ledInterval = 0;
    } 
#endif

}

/*
 * Call the Update Function for the Outputs (removed FASTRUN)
 */
void writeOutputs() {
  
#ifdef DEBUG
  // counts the ops/sec
  n++;
#endif
  
  // iterate through the values  
  for (p=0; p< 4; p++){
  
    // update the cv
    cvOutputs[p]->Update();

  } 
}


/*
 * Wire Callback
 */
void receiveEvent(size_t len) {

#ifdef DEBUG
  // set the back LED active to indicate data transfer
  Serial.printf("Event received of size %d \n", len);
  digitalWrite(LED, HIGH);
  ledOn = true;
  ledInterval = millis() + LEDINTERVAL;
#endif

  // parse the response
  TxResponse response = TxHelper::Parse(len);

  // act on the command
  actOnCommand(response.Command, response.Output, response.Value);
  
}


/*
 * Act on the Commands Delivered to the TXo
 */
void actOnCommand(byte cmd, byte out, int value){
  
  // zero-adjust the output number
  targetOutput = out;

  if (targetOutput < 0) return;
  
#ifdef DEBUG
  Serial.printf("Action: %d, Output: %d, Value: %d\n", cmd, targetOutput, value);
#endif

  unsigned long ms = millis();
  
  switch(cmd) {
    
    case TO_CV_SET:
      // set the value directly - no slew
      cvOutputs[targetOutput]->SetValue(value << 1);
      break;
    
    case TO_CV:     
      // set the target value and slew to it
      cvOutputs[targetOutput]->TargetValue(value << 1); 
      break;  

    case TO_CV_SLEW:
      // set the slew value
      cvOutputs[targetOutput]->SetSlew(value, 0);
      break;
      
    case TO_CV_SLEW_S:
      // set the slew value
      cvOutputs[targetOutput]->SetSlew(value, 1);
      break;
    
    case TO_CV_SLEW_M:
      // set the slew value
      cvOutputs[targetOutput]->SetSlew(value, 2);
      break;

    case TO_CV_OFF:
      // set the offset
      cvOutputs[targetOutput]->SetOffset(value << 1);
      break;

    case TO_CV_QT:
      // Set Pulse Time Format Trigger
      cvOutputs[targetOutput]->TargetQuantizedValue(value);
      break;
      
    case TO_CV_QT_SET:
      // Set Pulse Time Format Trigger
      cvOutputs[targetOutput]->SetQuantizedValue(value);
      break;

    case TO_CV_N:
      // Set Pulse Time Format Trigger
      cvOutputs[targetOutput]->TargetNote(value);
      break;
      
    case TO_CV_N_SET:
      // Set Pulse Time Format Trigger
      cvOutputs[targetOutput]->SetNote(value);
      break;
      
    case TO_CV_SCALE:
      // Set Pulse Time Format Trigger
      cvOutputs[targetOutput]->SetQuantizationScale(value);
      break;
      
    case TO_CV_LOG:
      // Enable Logarithmic Transformationn
      cvOutputs[targetOutput]->SetLog(value);
      break;

    case TO_OSC:
      cvOutputs[targetOutput]->TargetVOct(value);
      break;

    case TO_OSC_SET:
      cvOutputs[targetOutput]->SetVOct(value);
      break;

    case TO_OSC_QT:
      cvOutputs[targetOutput]->TargetQuantizedVOct(value);
      break;

    case TO_OSC_QT_SET:
      cvOutputs[targetOutput]->SetQuantizedVOct(value);
      break;
      
    case TO_OSC_FQ:
      // 
      cvOutputs[targetOutput]->TargetFrequency(value);
      break;
 
    case TO_OSC_FQ_SET:
      // 
      cvOutputs[targetOutput]->SetFrequency(value);
      break;

    case TO_OSC_N:
      cvOutputs[targetOutput]->TargetOscNote(value);
      break;
      
    case TO_OSC_N_SET:
      cvOutputs[targetOutput]->SetOscNote(value);
      break;
           
    case TO_OSC_LFO:
      // 
      cvOutputs[targetOutput]->TargetLFO(value);
      break;
      
    case TO_OSC_LFO_SET:
      // 
      cvOutputs[targetOutput]->SetLFO(value);
      break;
      
    case TO_OSC_SYNC:
      // 
      cvOutputs[targetOutput]->Sync();
      break;
      
    case TO_OSC_PHASE:
      // 
      cvOutputs[targetOutput]->SetPhaseOffset(value);
      break;
      
    case TO_OSC_WAVE:
      // 
      cvOutputs[targetOutput]->SetWaveform(value);
      break;
      
    case TO_OSC_WIDTH:
      // 
      cvOutputs[targetOutput]->SetWidth(value);
      break;
      
    case TO_OSC_RECT:
      // 
      cvOutputs[targetOutput]->SetRectify(value);
      break;
      
    case TO_OSC_SCALE:
      // 
      cvOutputs[targetOutput]->SetOscQuantizationScale(value);
      break;
      
    case TO_OSC_SLEW:
      // 
      cvOutputs[targetOutput]->SetFrequencySlew(value, 0);
      break;
      
    case TO_OSC_SLEW_S:
      // 
      cvOutputs[targetOutput]->SetFrequencySlew(value, 1);
      break;
      
    case TO_OSC_SLEW_M:
      // 
      cvOutputs[targetOutput]->SetFrequencySlew(value, 2);
      break;
      
    case TO_OSC_CYC:
      // 
      cvOutputs[targetOutput]->TargetCycle(value, 0);
      break;
      
    case TO_OSC_CYC_S:
      // 
      cvOutputs[targetOutput]->TargetCycle(value, 1);
      break;
      
    case TO_OSC_CYC_M:
      // 
      cvOutputs[targetOutput]->TargetCycle(value, 2);
      break;
      
    case TO_OSC_CYC_SET:
      // 
      cvOutputs[targetOutput]->SetCycle(value, 0);
      break;
      
    case TO_OSC_CYC_S_SET:
      // 
      cvOutputs[targetOutput]->SetCycle(value, 1);
      break;
      
    case TO_OSC_CYC_M_SET:
      // 
      cvOutputs[targetOutput]->SetCycle(value, 2);
      break;

    case TO_OSC_CTR:
      //
      cvOutputs[targetOutput]->SetCenter(value << 1);
      break;

    case TO_ENV_ACT:
      // 
      cvOutputs[targetOutput]->SetEnvelopeMode(value);
      break;
      
    case TO_ENV_ATT:
      // 
      cvOutputs[targetOutput]->SetAttack(value, 0);
      break;
      
    case TO_ENV_ATT_S:
      // 
      cvOutputs[targetOutput]->SetAttack(value, 1);
      break;
      
    case TO_ENV_ATT_M:
      // 
      cvOutputs[targetOutput]->SetAttack(value, 2);
      break;

    case TO_ENV_DEC:
      // 
      cvOutputs[targetOutput]->SetDecay(value, 0);
      break;

    case TO_ENV_DEC_S:
      // 
      cvOutputs[targetOutput]->SetDecay(value, 1);
      break;

    case TO_ENV_DEC_M:
      // 
      cvOutputs[targetOutput]->SetDecay(value, 2);
      break;
      
    case TO_ENV_TRIG:
      // 
      cvOutputs[targetOutput]->TriggerEnvelope();
      break;
      
    case TO_ENV_EOR:
      // 
      cvOutputs[targetOutput]->SetEOR(value - 1);
      break;
      
    case TO_ENV_EOC:
      // 
      cvOutputs[targetOutput]->SetEOC(value - 1);
      break;

    case TO_ENV_LOOP:
      // 
      cvOutputs[targetOutput]->SetLoop(value);
      break;

    case TO_TR:
      // Set Trigger Value
      triggerOutputs[targetOutput]->SetState(value > 0);    
      break;

    case TO_TR_TOG:
      // Toggle Trigger State
      triggerOutputs[targetOutput]->ToggleState();    
      break;

    case TO_TR_TIME:
       // Set Pulse Time for Trigger
      triggerOutputs[targetOutput]->SetTime(value, 0);    
      break;
      
    case TO_TR_TIME_S:
       // Set Pulse Time for Trigger
      triggerOutputs[targetOutput]->SetTime(value, 1);    
      break;
      
    case TO_TR_TIME_M:
       // Set Pulse Time for Trigger
      triggerOutputs[targetOutput]->SetTime(value, 2);    
      break;

    case TO_TR_PULSE:
      // Pulse the Trigger
      triggerOutputs[targetOutput]->Pulse();
      break;

    case TO_TR_POL:
       // Set the Trigger's Polarity
      triggerOutputs[targetOutput]->SetPolarity(value != 0); 
      break;

    case TO_TR_PULSE_DIV:
      // Set Clock Divider
      triggerOutputs[targetOutput]->SetDivision(value);
      break;

    case TO_TR_M_MUL:
      // Set Clock Divider
      triggerOutputs[targetOutput]->SetMultiplier(value);
      break;

    case TO_TR_M_ACT:
      // Set Clock Divider
      triggerOutputs[targetOutput]->SetMetro(value, ms);
      break;

    case TO_TR_M:
       // Set Pulse Time for TR Metro
      triggerOutputs[targetOutput]->SetMetroTime(value, 0);    
      break;
      
    case TO_TR_M_S:
       // Set Pulse Time for TR Metro
      triggerOutputs[targetOutput]->SetMetroTime(value, 1);    
      break;
      
    case TO_TR_M_M:
       // Set Pulse Time for TR Metro
      triggerOutputs[targetOutput]->SetMetroTime(value, 2);    
      break;
        
    case TO_TR_M_BPM:
       // Set Pulse Time for TR Metro
      triggerOutputs[targetOutput]->SetMetroTime(value, 3);    
      break;
              
    case TO_TR_M_SYNC:
       // Sync Pulse Time for TR Metro
      triggerOutputs[targetOutput]->Sync();    
      break;

    case TO_M_ACT:
      // Set Clock Divider
      for (int w = 0; w < 4; w++)
        triggerOutputs[w]->SetMetro(value, ms);
      break;

    case TO_M:
       // Set Pulse Time for TR Metro
      for (int w = 0; w < 4; w++)
        triggerOutputs[w]->SetMetroTime(value, 0);    
      break;
      
    case TO_M_S:
       // Set Pulse Time for TR Metro
      for (int w = 0; w < 4; w++)
        triggerOutputs[w]->SetMetroTime(value, 1);    
      break;
      
    case TO_M_M:
       // Set Pulse Time for TR Metro
      for (int w = 0; w < 4; w++)
        triggerOutputs[w]->SetMetroTime(value, 2);    
      break;
        
    case TO_M_BPM:
       // Set Pulse Time for TR Metro
      for (int w = 0; w < 4; w++)
        triggerOutputs[w]->SetMetroTime(value, 3);    
      break;

    case TO_M_COUNT:
       // Set Count for M Repeats
      for (int w = 0; w < 4; w++)
        triggerOutputs[w]->SetMetroCount(value); 
      break;
             
    case TO_M_SYNC:
       // Sync Pulse Time for TR Metro
      for (int w = 0; w < 4; w++)
        triggerOutputs[w]->Sync(ms);
      break;
        
    case TO_TR_WIDTH:
       // Set Pulse Time for TR Metro
      triggerOutputs[targetOutput]->SetWidth(value);    
      break;

    case TO_TR_M_COUNT:
       // Set Count for M Repeats
      triggerOutputs[targetOutput]->SetMetroCount(value);    
      break;

    case TO_TR_PULSE_MUTE:
       // Mute/Unmute the appropriate output
      triggerOutputs[targetOutput]->SetMute(value == 1);  
      break;
      
    case TO_KILL:
      for(int w=0; w<4; w++){
        
        // Kill Each Trigger
        triggerOutputs[w]->Kill();
        
        // stop all slewwing
        cvOutputs[w]->Kill();
        
      } 
      break;

    case TO_TR_INIT:
       // initialize the TR Output
       triggerOutputs[targetOutput]->Reset();
      break;

    case TO_CV_INIT:
       // initialize the CV Output
       cvOutputs[targetOutput]->Reset();
      break;

    case TO_INIT:
       // initialize all TR and CV Outputs
       for(int w=0; w<4; w++){
          triggerOutputs[w]->Reset();
          cvOutputs[w]->Reset();
       }
      break;

    case TO_CV_CALIB:
      // turns the current value and offest into a permanent offset
      writeCalibrationValue(targetOutput, cvOutputs[targetOutput]->Calibrate());
      break;
      
    case TO_CV_RESET:
      // returns the permanent offset to 0
      cvOutputs[targetOutput]->ResetCalibration();
      writeCalibrationValue(targetOutput, 0);
      break;
      
    case TO_ENV:
      // gates the envelope on and off
      cvOutputs[targetOutput]->SetENV(value);
      break;
      
    
  }

}

/*
 * Writes the calibration data to the Teensy's EEPROM
 */
void writeCalibrationValue(int index, int value){
  #ifdef DEBUG
  Serial.printf("writing calibration for CV[%d] = %d\n", index, value);
  #endif  
  int address = 4 + (2 * index);
  uint16_t uInt16t = (uint16_t)value;
  byte one = uInt16t & 255;
  byte two = uInt16t >> 8;
  if (EEPROM.read(address) != one) EEPROM.write(address, one);
  if (EEPROM.read(++address) != two) EEPROM.write(address, two);  
}

/*
 * reads the calibration data from the Teensy's EEPROM
 */
void readCalibrationData(){
  
  #ifdef DEBUG
  Serial.print("checking for calibration data\n");
  #endif  
  
  int rPos = 0;

  uint16_t uInt16t = 0;
  
  // Look for the TXo Tag
  // "TXo "
  if (EEPROM.read(rPos++) == 84 && EEPROM.read(rPos++) == 88 && EEPROM.read(rPos++) == 111 && EEPROM.read(rPos++) == 32) {
  
    #ifdef DEBUG
    Serial.print("TXo data island found; reading calibration data\n");
    #endif  
   
    for (int i=0; i < 4; i++) {
      uInt16t = EEPROM.read(rPos) + (EEPROM.read(rPos + 1) << 8);
      rPos += 2;
      #ifdef DEBUG
      Serial.printf("CV[%d]: %d\n", i, (int16_t)uInt16t);
      #endif  
      cvOutputs[i]->SetCalibrationValue((int16_t)uInt16t);
    }
  
  } else {
    
    #ifdef DEBUG
    Serial.print("initializing eeprom\n");
    #endif
    
    rPos = 0;
    // "TXo "
    EEPROM.write(rPos++, 84);
    EEPROM.write(rPos++, 88);
    EEPROM.write(rPos++, 111);
    EEPROM.write(rPos++, 32);
    
    // initialize zeros for the four values we store
    for (int i=0; i<8; i++){
      EEPROM.write(rPos++, 0);
    }
  }
  
}

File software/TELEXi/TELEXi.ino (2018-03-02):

/*
 * TELEXi Eurorack Module
 * (c) 2016, 2017 Brendon Cassidy
 * MIT License
 */
 
// debug flag turns on serial debugging over USB
// #define DEBUG 1

// i2c Wire library (for Teensy)
#include <i2c_t3.h>
#include <EEPROM.h>

// support libraries
#include "telex.h"
#include "Quantizer.h"
#include "AnalogReader.h"
#include "TxHelper.h"

/*
 * Ugly Globals
 */

// i2c pullup setting
bool enablePullups = false;

// config inputs
int configPins[] = { 2, 1, 0 };
int configID = TI;

// logging in the loop
#define LOGINTERVAL 250 // 1000
#define LEDINTERVAL 1000

// inputs, readers and storage
int inputs[] = { A6, A7, A8, A9, A1, A3, A0, A2 };
AnalogReader *analogReaders[8];
QuantizeResponse qresponse;
int volatile inputValue[8];
int volatile quantizedValue[8];
int volatile quantizedNote[8];

// read timer and its local variables
IntervalTimer readTimer;
int p = 0;

// quantizers and quantizer state
Quantizer *quant[8];

// i2c transmission stuff
byte buffer[4];
int targetOutput = 0;

// i2c slave transmit
byte activeInput = 0;
byte activeMode = 0;

#ifdef DEBUG
unsigned long logInterval = 0;
// led status for tx/rx
int LED = 13;
unsigned long ledInterval;
bool ledOn = false;
#endif

/*
 * Setup Function
 */
void setup() {

  int i;
  
  // config
  int cfg = 0;
  for (i=0; i < 3; i++){
    pinMode(configPins[i], INPUT);
    cfg += digitalRead(configPins[i]) << i;
  }
  configID += cfg;  

  // TELEXi uses the standard Teensy analog inputs which have 13 bit usable resolution
  analogReadResolution(13);

  // debugging nonsense
#ifdef DEBUG
  // set the behind-the-scenes LED output pin
  pinMode(LED, OUTPUT);
  logInterval = millis() + LOGINTERVAL;
  Serial.begin(9600);
  // wait for debugging connection   
  while (!Serial);
  Serial.printf("ConfigID: %d\n", configID);
#endif

  // initialize the readers, input values and quantizers
  for (i=0; i <8; i++) {
    analogReaders[i] = new AnalogReader(inputs[i], i >= 4);
    inputValue[i] = 0;
    quant[i] = new Quantizer(0);
  }

  // read the calibration data from EEPROM
  readCalibrationData();

#ifdef DEBUG
  // take a quick pause (for the calibration data to print for debugging)
  delay(1000);
#endif

  // start the read timer
  readTimer.begin(readInputs, 1000); // 500

  // enable i2c and connect the event callbacks
  Wire.begin(I2C_SLAVE, configID, I2C_PINS_18_19, enablePullups ? I2C_PULLUP_INT : I2C_PULLUP_EXT, I2C_RATE_400); // I2C_RATE_2400 // I2C_PULLUP_EXT
  Wire.onReceive(receiveEvent);  
  Wire.onRequest(requestEvent);

}

/*
 * the read input timer interrupt
 * need to be careful with what we access and do here
 * this function is pushing it with the quantization and stuff
 */
void readInputs(){
  // loop through the 8 inputs and store the latest value 
  for (p=0; p < 8; p++){
    inputValue[p] = analogReaders[p]->Read();
    // handle the quantized response
    qresponse = quant[p]->Quantize(inputValue[p]);
    quantizedValue[p] = qresponse.Value;
    quantizedNote[p] = qresponse.Note;
  }
}

/*
 * a simple debugging print loop - all other actions happen in the callbacks and timers
 */
void loop() {

#ifdef DEBUG
    // print stuff
    if (millis() >= logInterval) {
        for (int l=0; l < 8; l++)
          Serial.printf("%d=%d; ", l, inputValue[l]);
        Serial.printf("\n");
        logInterval = millis() + LOGINTERVAL;
    }

    // turn off LED
    if (ledOn && millis() > ledInterval) {
      ledOn = false;
      ledInterval = 0;
    }
#endif
  
}


/*
 * receive the event from the i2c wire library
 */
void receiveEvent(size_t len) {

#ifdef DEBUG
  // set LED active to indicate data transfer
  digitalWrite(LED, HIGH);
  ledOn = true;
  ledInterval = millis() + LEDINTERVAL;
#endif

  // parse the response
  TxResponse response = TxHelper::Parse(len);

  // true command our setting of the input for a read?
  if (len == 1) {
    
    TxIO io = TxHelper::DecodeIO(response.Command);
    
#ifdef DEBUG
    Serial.printf("Port: %d; Mode: %d [%d]\n", io.Port, io.Mode, response.Command);
#endif
    
    // this is the single byte that sets the active input
    activeInput = io.Port;
    activeMode = io.Mode;
    
  } else {
    // act on the command
    actOnCommand(response.Command, response.Output, response.Value);
  }
  
}

/*
 * this is when the master is requesting data from an input
 * we return the int (which is cast to unsigned so the sign can survive the transit)
 */
void requestEvent() {

  // disable interrupts. get and cast the value
  uint16_t shiftReady = 0;
  switch(activeMode){
    case 1:
      noInterrupts();
      shiftReady = (uint16_t)quantizedValue[activeInput];
      interrupts();
      break;
    case 2:
      noInterrupts();
      shiftReady = (uint16_t)quantizedNote[activeInput];
      interrupts();
      break;
    default:
      noInterrupts();
      shiftReady = (uint16_t)inputValue[activeInput];
      interrupts();
      break;
  }
  
#ifdef DEBUG
  Serial.printf("delivering: %d; value: %d [%d]\n", activeInput, inputValue[activeInput], shiftReady);
#endif

  // send the puppy as a pair of bytes
  Wire.write(shiftReady >> 8);
  Wire.write(shiftReady & 255);
}


/*
 * act on commands delivered over i2c
 * command list is in the shared telex.h file
 */
void actOnCommand(byte cmd, byte out, int value){

  byte outHelper = out;

  // act on your commands
  switch (cmd) {

    case TI_IN_SCALE:
      outHelper += 4;
    case TI_PARAM_SCALE:
      quant[outHelper]->SetScale(value);
      break;

    case TI_IN_TOP:
      outHelper += 4;
    case TI_PARAM_TOP:
      analogReaders[outHelper]->SetTop(value);
      break;

    case TI_IN_BOT:
      outHelper += 4;
    case TI_PARAM_BOT:
      analogReaders[outHelper]->SetBottom(value);
      break;

    case TI_IN_CALIB:  
      outHelper += 4;  
    case TI_PARAM_CALIB:
      analogReaders[outHelper]->Calibrate(value);
      break;    

    case TI_STORE:
      saveCalibrationData();
      break;

    case TI_RESET:
      resetCalibrationData();
      break;
  }

#ifdef DEBUG
  Serial.printf("Action: %d, Output: %d\n", cmd, outHelper);
#endif
  
}
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

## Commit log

2016-12-29 added PDF of schematic
2017-01-08 added a bunch of supporting materials (some in-progress) and updated the command documentation
    [txi.scad, txi.stl, txo_bottom.scad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]
2017-01-13 set i2c to 400mHz; TXi build maps; assembly_frame thing
    [assembly_frame.scad, assembly_frame.stl]
2017-01-14 build maps and updated BOMs
    [TELEXi-BOM.xlsx, TELEXo-BOM.xlsx]
2017-01-14 changed i2c pullup value from test
2017-01-14 fixed a couple of links
2017-01-15 added some margin to the stencil frame, updated the TELEX header file and made a global for pullup
    [txi.scad, txi.stl, txo_bottom.scad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]
2017-02-02 bugfixes for envelopes and some 3d printed build stuff added
    [telex_generic.scad, telex_generic.stl, telexi_generic.scad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]
2017-02-07 working changes
    [txo_top_multi.scad, txo_top_multi.stl]
2017-02-07 fixed LED issue for specific sequence of positive and negative values; optimized oscillator phase code
    [CVOutput.cpp, Oscillator.h]
2017-02-07 telex BOM update; command-reference update
    [TELEXo-BOM.xlsx]
2017-02-12 updated build map for typo and added the multi-board frames with proper spacing
    [txi_bottom_multi.scad, txi_bottom_multi.stl, txi_top_multi.scad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]
2017-02-13 expanded tolerances for jacks and LEDs
2017-02-18 added functions for TI mapping, CYC setting of oscillation and trigger width percentage of TR.M
    [AnalogReader.cpp, CVOutput.cpp, CVOutput.h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]
2017-02-18 β instead
2017-02-18 added count parameter and an LED brightness slope
2017-03-21 updated assembly frame, BOMs and TriggerOutput behavior for TR.M
    [TELEXi-BOM.xlsx, TELEXo-BOM.xlsx, assembly_frame.scad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]
2017-06-03 New Telex Operators:
    - TO.TR.PULSE.MUTE/TO.TR.P.MUTE - mute/unmute a TR PULSE output
    - TO.TR.INIT/TO.CV.INIT/TO.INIT - all are now device native
    - TO.OSC.CTR - set the centerpoint for oscillation
    - TO.ENV.EOR/TO.ENV.EOC - bind local trigger outputs to points in the envelope
    - TO.M.ACT - global activation for all 4 metronomes
    - TO.M - set the ms rate for all 4 metronomes
    - TO.M.S - set the seconds rate for all 4 metronomes
    - TO.M.M - set the minutes rate for all 4 metronomes
    - TO.M.BPM - set the BPM for all 4 metronomes
    - TO.M.SYNC - sync all 4 metronomes
    - TO.M.COUNT - set the count property for all 4 metronomes
    - TO.TR.M.MUL - clock multiplier for each local metronome
    - TO.CV.LOG - logarith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
    [CVOutput.cpp, CVOutput.h, TELEXo.ino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]
2017-06-03 micro bug with offsets when envelope is being triggered
    [CVOutput.cpp]
2017-06-09 optimized memory and fixed mid-envelope rate updates
    [CVOutput.cpp, CVOutput.h, TELEXo.ino]
2017-11-16 updated build map and BOM for 1k trigger out resistor reversion; massively improved the smoothing method for the TXi reads; added back the Teensy-specific i2c library for the TXo (oops)
    [TELEXo-BOM.xlsx]
2017-12-03 updated txi code to fix bug in calibration and reduce sampling interval to 1ms
    [AnalogReader.cpp, TELEXi.ino]
2018-01-09 v.019 BETA - bug fixes for CV, jumper settings, and new envelope operators
    [AnalogReader.cpp, CVOutput.cpp, CVOutput.h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]
2018-01-22 fixes for TXi address identification
    [TELEXi.ino]
2018-02-22 updated BOM files
    [TELEXi-BOM.xlsx, TELEXo-BOM.xlsx]
2018-02-24 envelope fix, refactoring, inital 3.6 support, new wavetables
    [CVOutput.cpp, CVOutput.h, Oscillator.h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]
2018-03-02 bom fix; txo envelope recomputation enhancement; telexi smoothing enhancement
    [TELEXo-BOM.xlsx]
2018-03-19 implemented fixed point polyblep for saw and square waves on txo+
    [Oscillator.h]
2018-03-19 switched to native generation of sawtooth wave

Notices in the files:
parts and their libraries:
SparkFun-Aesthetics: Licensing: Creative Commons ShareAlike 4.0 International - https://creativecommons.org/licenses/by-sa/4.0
